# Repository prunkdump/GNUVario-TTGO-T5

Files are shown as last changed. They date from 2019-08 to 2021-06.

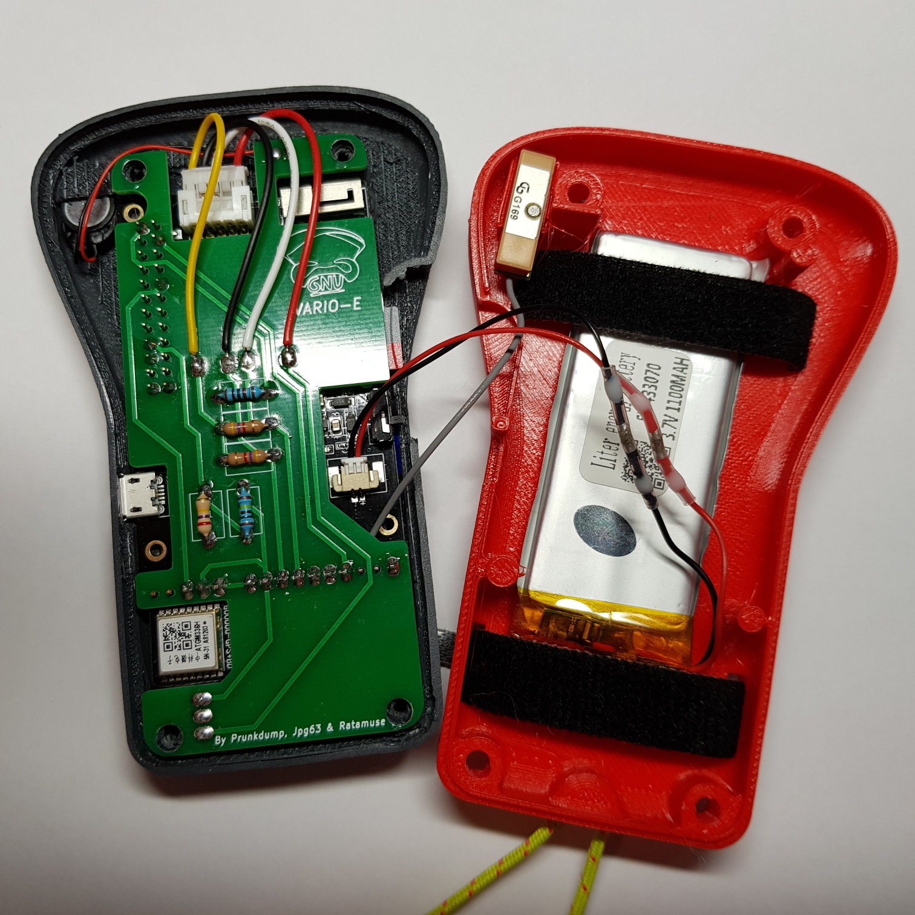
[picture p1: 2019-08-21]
PCB/KiCad GNU Vario E V1.12/Pictures/PCB soldered back.jpg

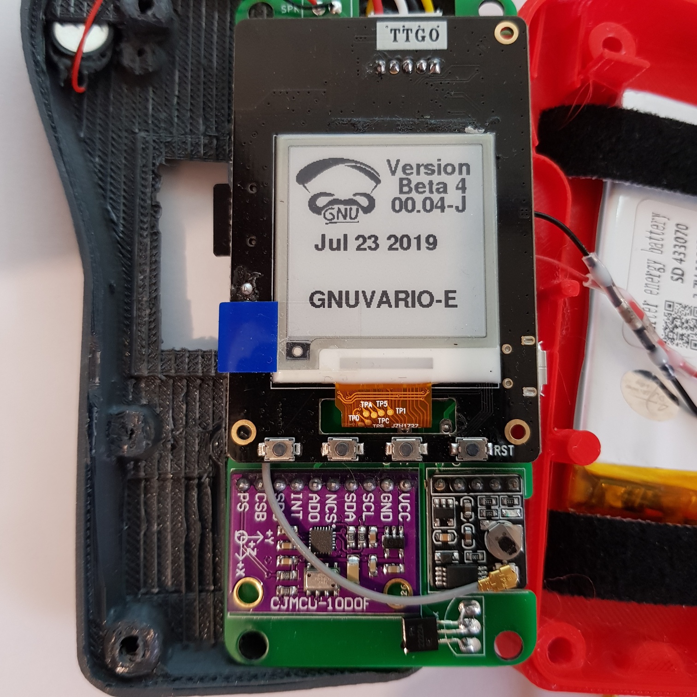
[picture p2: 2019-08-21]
PCB/KiCad GNU Vario E V1.12/Pictures/PCB soldered front.jpg

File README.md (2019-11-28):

# Gnuvario_for_TTGO-T5
# GNUVARIO-E     Stable version ---
# GNUVARIO-E     Developpement version 0.6 beta 7
# PCB            version 2.1
# 3D CASE        version 2.01

 v 0.1                              beta 1 version                     
 v 0.2     beta 1      23/06/19     debug VarioScreen                        
 v 0.3     beta 1      25/06/19     correction mesure tension          
                                    correction mesure de vitesse       
 v 0.3     beta 2      26/06/19     correction save IGC                                                 
 v 0.4     beta 1      03/07/19     ajout la coupure du son            
 v 0.4     beta 2      06/07/19     ajout statistique                  
 v 0.4     beta 3      18/07/19     Correction gestion Eeprom          
                                    Correction tache affichage          
                                    Ajout delete task display          
                                    Correction affichage statistique   
 v 0.4      beta 4      22/07/19    Correction effacement screendigit                               
                                    Correction affichage duree du vol  
                                    Correction affichage statistique   
                                    Modification FlightHistory         
                                    Ajout parametre flighthistory dans 
                                    SETTINGS.TXT                       
                                    Enregistrement des statistique     
                                    toutes les 60sec - reduction des   
                                    cycle d'ecriture dans la mémoire   
                                    flash de l'ESP32                   
 v 0.4     beta 5    24/07/19       Ajout TrendDigit                   
                                    Modification TrendLevel            
                                    Modification screendigit           
                                    Correction démarrage du vol    
 v 0.4     beta 6    25/07/19       Ajout NO_RECORD                                                                                          
                                    Correction TWOWIRESCHEDULER        																		
 
 v 0.4     beta 7    05/08/19       Désactivation enregistrement stat  
                                    pour eviter le bug du plantage      
                                    Ajout paramettre wifi              
                                    Modification SETTINGS.TXT v1.2     
 v 0.4     beta 8    06/08/19       Ajout icone Norecord               
                                    Correction bug statistique         
                                    Raffraichissement de l'ensemle de  
                                    l'écran toutes les 30sec           
 v 0.5     beta 1    10/08/19       Ajout Gestionnaire d'erreur ESP32  
                                    Mise à jour via SDCARD /update.bin 
                                    Ajout Serveur Web update/download  
                                    Ajout HAVE_WIFI                    
                                    Ajout BT                           
 v 0.5     beta 2    20/08/19       Ajout dans hardwareConfig32 de la  
                                    version du PCB et de la TTGO       
                                    Ajout lecture de la temperature    
                                    MAJ OTA Web serveur                
                                    Ajout changement de page           
                                    Ajout 2ème ecran                   

 v 0.5     beta 3  25/08/19         Ajout LOW/HIGH level cmd ampli     
                                    Ajout ecran reglage volume du son  
                                    Correction Bug bouton              

 v 0.5     beta 4  30/08/19         Ajout écran stat 
                                    Modification librairie ToneHAL 
																		Correction bug d'affichage mineurs

 v 0.5     beta 5  31/08/19         Correction bg reglage volume       
                                    Ajout commande ampli dans loop     
                                    pour test                          
 
 v 0.5     beta 6  04/09/19         Changement librairies MS5611 et MPU9250                                                             
                                    Modification de la calibration de l'altitude par le GPS                  
                                    Ajout d'un coeficiant de compensation de temperature             
                                    Modification de la séquence de démarrage de l'enregistrement   
																		
 v 0.5     beta 7  10/09/19         Ajout choix des pin SDA, SCL                                                                                                       
                                    Modification des librairies du MPU9250 / ajout fonctions de                                                                                   
                                    Calibration                                                      
                                    Ajout Son de monté variable                                      
                                    Modification de la sequence de démarrage -                       
                                    allongement du temps de l'écran de stat à 6 sec                  
                                    init MS5611 avant ecran stat, ajout acquisition durant ecran     
                                    stat et init kalman après                                        
                                    Ajout d'un paramettre de nombre d'acquisition du GPS avant        
                                    la mise à jour de Altitude Barometrique                          
                                    Modification librairie EEPROM                                    
																		
                   Developpement à venir                               
                                                                                                                                    
 V0.4                                                                                                                                          																												
 bug affichage finesse  
 
 V0.5                                                                  
 voir réactivité des données GPS                                                                     
 Probleme consommasion - SDcard - deep slepp                                                         
                                                                                                     
 v0.6                                                                                                   
 MODIF - Refaire gestion Eeprom avec preference                                                      
 AJOUT - Calibration MPU                                                                                                              
 AJOUT - gestion du MPU par Interruption                                                             
 BUG   - reboot à l'init du MPU  - nan lors du first alti                                            
 BUG   - blocage MPU - plus de valeur valide                                                         
 BUG   - temperature                                                                                 
 BUG   - DISPLAY_OBJECT_LINE object ligne ne fonctionne pas                                          
 AJOUT - Créer une bibliothèque de log (debug)  avec fichier de log                                  
 BUG   - Alti erreur deep sleep non validé                                                               
 BUG   - Norcissement de l'écran                                                                     
                                                                                                     
 VX.X                                                                                                
 Paramètrage des écrans                                                                             
 Gérer le son via le DAC                                                                             
 revoir volume du son ToneESP32                                                                      
 Refaire gestion du son (parametrage via xctracer)                                                   
 Ecran position afficher les coordonées GPS, la boussole, et l'altitude                                                                                                     
 Création dynamique des objets screen                                                                
 Sens et vitesse du vent                                                                             
 Carnet de vol (10 derniers vols)                                                                    
 verifier fonctionnement BT                                                                          
 Recupération vol via USB                                                                                                                                                                    
 Ecran 2.9'' en vertical                                                                             

                    Fonctionalitées   
		
  Version 0		
    Vario précis avec capteur de pression et accéleromètres
    GPS
    Enregistrement des vols sur carte SD
    Affichage sur ecran E-Ink
    Affichage du vario, de l'altitude, de la vitesse sol,
    de l'heure, du temps de vol, ...
                                                                       
  Version 0.3                                                                                                                               
    Parametre utilisateur dans fichier SETTINGS.TXT                    
    Coupure du son via le bouton central (en vol)                      
                                                                       
  Version 0.4                                                          
    Statistiques de Vol                                                
    taux de chute et finesse                                           
    indicateur de monte/descente 
    Désactiver l'enregistrement des vols		
                                                                       
  Version 0.5                                                            
    Mise à jour via la carte SD (update.bin)                            
    Récupération des vol via Wifi                                         
    Mise à jour via Wifi                                                  
    Upload des fichiers de configuration via Wifi                         
    Ajout Bluetooth                                                       
    Multi-écran (ajout 2ème page / gestion des bouton droit et gauche)    
    Affichage de la température        
		Page de configuration du volume sonore   
    Page de statistique accessible via les boutons    	
		Mise en veille automatique en cas de batterie trop faible               
                                                                              
  Version 0.6                                                              
    Page de calibration                                                      
    Mise en veille prolongée par bouton                                                  
    Ajout gestion des écran 2.9'' et 2.13''                                  
    Ajout du serveur Web sur SDCARD                                          
    Activation du Bluetooth en parametre dans le fichier de configuration       
    Ajout de titre au dessus des champs de données                          
    Ajout de nouveau objects screen - ligne - rose des vents                
    Modification de l'organisation des fichiers sur la carte SD                
    Ajout compensation de température         
    Ajout correction d'altitude GPS                     
    Modification calibration alti GPS - 5 mesures puis moyenne de l'altitude sur 10 mesures avant de calibrer le barometre                   
    3 fichiers de paramètrage params.jso, wifi.cfg, variocal.cfg               
    Gestion automatique de la mise à jour du fichier params.jso en cas d'ajout ou de suppréssion de champs                                       
    Mise en veille en cas d'inactivité, paramètrable - 0 infini

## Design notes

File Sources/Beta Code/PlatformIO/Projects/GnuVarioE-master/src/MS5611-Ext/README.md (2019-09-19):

Arduino-MS5611
===============

MS5611 Barometric Pressure & Temperature Sensor Arduino Library

This library use I2C to communicate, 2 pins are required to interface.

Read more: http://www.jarzebski.pl/arduino/czujniki-i-sensory/czujnik-cisnienia-i-temperatury-ms5611.html

MS5611

MS5611

I need your help
----------------

July 31, 2017

In the near future I plan to refactoring the libraries. The main goal is to improve code quality, new features and add support for different versions of Arduino boards like Uno, Mega and Zero.

For this purpose I need to buy modules, Arduino Boards and lot of beer. 

If you want to support the further and long-term development of libraries, please help.

You can do this by transferring any amount to my PayPal account: paypal@jarzebski.pl

Thanks!

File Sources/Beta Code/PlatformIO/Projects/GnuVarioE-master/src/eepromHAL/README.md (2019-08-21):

# EEPROMHAL Library

EepromHAL is an arduino abstraction library for Eeprom management 
									
Multi-platform :
									Arduino Pro-Mini
									Atmel SAM D21 - MKZERO 
									Espressif ESP32
									
## Setting

	in eepromHAL.h

									EEPROM_SIZE 					Eeprom size alocation

									EEPROMHAL_EXTENDED		Activate extended function

##	VERSION 1.3.3

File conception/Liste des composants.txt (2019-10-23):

Gnuvario-E

Version 2.0

Liste des composant :

- une carte TTGO-T5 version 2.4 avec écran 1.54
[AE] ttgo-T5 v2.4

- CJMCU_117 MPU-9250+MS5611 Haute précision 9-Axes 10DOF
[AE] CJMCU 117
[EB] CJMCU 117

- GPS ATGM336H
[AE] ATGM336H
{EB] ATGM336H

- Batterie lipo 3.7V 1100mAH 30x70x4.3
[AE] lipo 3.7V 1100mAH 4.3
https://fr.aliexpress.com/item/32662685911.html?spm=a2g0s.9042311.0.0.e0e06c37J9dtAU

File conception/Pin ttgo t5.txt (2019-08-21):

*****************
MPU 9250 / MS5611
*****************
 
SDA_PIN 	21
SCL_PIN 	22

*******************
Ecran EPaper 1.54''
*******************

CS/SS 		GPIO 5
DC 		GPIO17
RST 		GPIO16
BUSY 		GPIO 4

MOSI		15
MISO		2
SCK		14

https://github.com/ZinggJM/GxEPD

****
LED
**** 

LED_BUILTIN 	22

*******
SDCard
*******

mySD.h

M5Stack.h

CS 		13
MOSI		15
MISO		2
SCK		14

*********
Boutons
*********

M4Stack.h

Bouton A	38
Bouton B	37
Bouton C	39

************
Speaker
************

PWM/DAC		25 ou 26

 NS4148, http://www.chipsourcetek.com/Uploads/file/20151207193630_0605.pdf amplificateur audio mono 3W - Classe D connecté sur la pin GPIO 25

(XT_DAC_Audio) for ESP32  http://www.xtronical.com/the-dacaudio-library-download-and-installation/ 

pinAudioAmpEna	34

******************
GPS
******************

RX	IO19

******************************
Lecture de la charge batterie
******************************

tension  IO35	

Les données sont imparfaites sur internet. Je suis reparti de la base: Le shéma du Adafuit ESP32 HUZZAH feather. 
https://github.com/adafruit/Adafruit-HUZZAH32-ESP32-Feather-PCB

On y voit que le "pont diviseur" entre VBAT et l'entrée analogique A13 "sacrifiée" à la tâche de mesure de la tension batterie 
est constitué de deux résistances de 100K.

            vbat
             |
            100k
             |
  A13 IO35 ---
             |
            100k
             |
            GND

D'autre part dans le datasheet ESP32 on voit que l'ADC est sur 12 bits (0--4095) avec une "full range" à Vcc soit 
environ 3.2V (3.29 dans mon cas)

Donc :

La tension mesurée est V bat / 2
Le tout avec 0=0v et 4095=Vcc (3.2V)
Donc de facon générique l'entrée analogique est convertie en Volts par

U=analogRead/(4096/Vcc)
Donc pour VBAT sur A13

Vbat=2*analogRead/(4096/Vcc)

/*********************************/
Internal HALL Sensor
/*********************************/

/* 
 *  Copyright (c) 2018, circuits4you.com
 *  All rights reserved.
 * 
 * ESP32 Hall Sensor Example
 */

 #define LED 22
 
//================================================
//         Setup
//================================================
void setup() {
  Serial.begin(115200);
  pinMode(LED,OUTPUT);
}

//================================================
//         Loop
//================================================
void loop() { 
  int sensor = hallRead();  //Reads Hall sensor value
  Serial.print("Sensor Reading:");
  Serial.println(sensor);

  digitalWrite(LED,(sensor < 0) ? HIGH : LOW); //On board LED detects presence of magnet
  delay(500);
}

/*************************************************
Internal TEMPERATURE Sensor
/*************************************************

/* 
 *  https://circuits4you.com
 *  ESP32 Internal Temperature Sensor Example
 */

 #ifdef __cplusplus
  extern "C" {
 #endif

  uint8_t temprature_sens_read();

#ifdef __cplusplus
}
#endif

uint8_t temprature_sens_read();
//====================================================
//         Setup
//====================================================
void setup() {
  Serial.begin(115200);
}

//====================================================
//         Loop
//====================================================
void loop() {
  Serial.print("Temperature: ");
  
  // Convert raw temperature in F to Celsius degrees
  Serial.print((temprature_sens_read() - 32) / 1.8);
  Serial.println(" C");
  delay(1000);
}

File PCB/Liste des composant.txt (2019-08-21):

Gnuvario-E

Version 1.10

Liste des composant :

- une carte TTGO-T5 version 1.2 avec écran 1.54
[AE] ttgo-T5 v1.2

- CJMCU_117 MPU-9250+MS5611 Haute précision 9-Axes 10DOF
[AE] CJMCU 117
[EB] CJMCU 117

- GPS ATGM336H
[AE] ATGM336H
{EB] ATGM336H

- Batterie lipo 3.7V 1100mAH 30x70x4.3
[AE] lipo 3.7V 1100mAH 4.3
https://fr.aliexpress.com/item/32662685911.html?spm=a2g0s.9042311.0.0.e0e06c37J9dtAU

- Transistor S8050 ou equivalent (2N2222)
- R1 : 270k
- R2 : 1M
- R3 : 4.7k
- R4 : 4.7k
- R5 : 1k
Option connecteur 2 x 12 pins

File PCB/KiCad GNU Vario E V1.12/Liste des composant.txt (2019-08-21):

Gnuvario-E

Version 1.10

Liste des composant :

- une carte TTGO-T5 version 1.2 avec écran 1.54
- CJMCU_117 MPU-9250+MS5611 Haute précision 9-Axes 10DOF
- GPS ATGM336H
- Batterie lipo 3.7V 1100mAH 30x70x4.3
- Transistor S8050 ou equivalent
- R1 : 270k
- R2 : 1M
- R3 : 4.7k
- R4 : 4.7k
- R5 : 1k
Option connecteur 2 x 12 pins

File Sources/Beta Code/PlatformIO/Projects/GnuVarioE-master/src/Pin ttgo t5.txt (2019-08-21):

*****************
MPU 9250 / MS5611
*****************
 
SDA_PIN 	21
SCL_PIN 	22
INT		13
AD0		GND
NCS <-> PS

*******************
Ecran EPaper 1.54''
*******************

CS/SS 		5
DC 		17
RST 		16
BUSY 		4

MOSI		15
MISO		2
SCK		14

https://github.com/ZinggJM/GxEPD

****
LED
**** 

LED_BUILTIN 	22

*******
SDCard
*******

mySD.h

M5Stack.h

CS 		13
MOSI		15
MISO		2
SCK		14

*********
Boutons
*********

M4Stack.h

Bouton A	38
Bouton B	37
Bouton C	39

************
Speaker
************

PWM/DAC		25 
PWM/DAC exter   26
Shutdown	34

 NS4148, http://www.chipsourcetek.com/Uploads/file/20151207193630_0605.pdf amplificateur audio mono 3W - Classe D connecté sur la pin GPIO 25

(XT_DAC_Audio) for ESP32  http://www.xtronical.com/the-dacaudio-library-download-and-installation/ 

******************
GPS
******************

RX	IO19

******************************
Lecture de la charge batterie
******************************

tension  IO35	

Les données sont imparfaites sur internet. Je suis reparti de la base: Le shéma du Adafuit ESP32 HUZZAH feather. 
https://github.com/adafruit/Adafruit-HUZZAH32-ESP32-Feather-PCB

On y voit que le "pont diviseur" entre VBAT et l'entrée analogique A13 "sacrifiée" à la tâche de mesure de la tension batterie 
est constitué de deux résistances de 100K.

            vbat
             |
            100k
             |
  A13 IO35 ---
             |
            100k
             |
            GND

D'autre part dans le datasheet ESP32 on voit que l'ADC est sur 12 bits (0--4095) avec une "full range" à Vcc soit 
environ 3.2V (3.29 dans mon cas)

Donc :

La tension mesurée est V bat / 2
Le tout avec 0=0v et 4095=Vcc (3.2V)
Donc de facon générique l'entrée analogique est convertie en Volts par

U=analogRead/(4096/Vcc)
Donc pour VBAT sur A13

Vbat=2*analogRead/(4096/Vcc)

/*********************************/
Internal HALL Sensor
/*********************************/

/* 
 *  Copyright (c) 2018, circuits4you.com
 *  All rights reserved.
 * 
 * ESP32 Hall Sensor Example
 */

 #define LED 22
 
//================================================
//         Setup
//================================================
void setup() {
  Serial.begin(115200);
  pinMode(LED,OUTPUT);
}

//================================================
//         Loop
//================================================
void loop() { 
  int sensor = hallRead();  //Reads Hall sensor value
  Serial.print("Sensor Reading:");
  Serial.println(sensor);

  digitalWrite(LED,(sensor < 0) ? HIGH : LOW); //On board LED detects presence of magnet
  delay(500);
}

/*************************************************
Internal TEMPERATURE Sensor
/*************************************************

/* 
 *  https://circuits4you.com
 *  ESP32 Internal Temperature Sensor Example
 */

 #ifdef __cplusplus
  extern "C" {
 #endif

  uint8_t temprature_sens_read();

#ifdef __cplusplus
}
#endif

uint8_t temprature_sens_read();
//====================================================
//         Setup
//====================================================
void setup() {
  Serial.begin(115200);
}

//====================================================
//         Loop
//====================================================
void loop() {
  Serial.print("Temperature: ");
  
  // Convert raw temperature in F to Celsius degrees
  Serial.print((temprature_sens_read() - 32) / 1.8);
  Serial.println(" C");
  delay(1000);
}

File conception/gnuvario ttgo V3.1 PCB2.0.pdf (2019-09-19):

## GNUVARIO-E TTGO T5 V1.6 ou 2.4

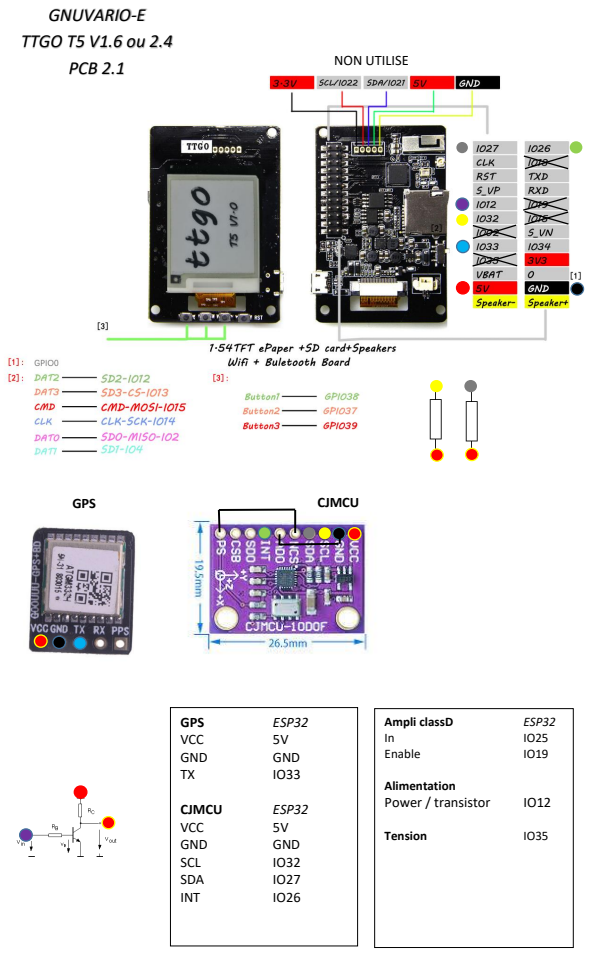
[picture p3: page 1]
GPS; ESP32; VCC; GND; CJMCU; SCL; SDA; INT; Ampli classD; Enable; Alimentation; Power / transistor; Tension; PCB 2.1; NON UTILISE

MPU 9250 / MS5611

SDA | IO27
SCL | IO32
INT | IO26

Ecran EPaper 1.54''

CS/SS | IO05
DC | IO17
RST | IO16
BUSY | IO04
MOSI | IO15
MISO | IO02
SCK | IO14

SDCard

CS | IO13
MOSI | IO15
MISO | IO02
SCK | IO14

Boutons

Bouton A | IO38
Bouton B | IO37
Bouton C | IO39

HP

PWM/DAC | IO25
Ampli (EN) | IO19

GPS

RX | IO33

Lecture de la charge batterie

Tension | IO35

Alimentation

Transistor | IO12

IO02 | MISO | SDCARD / E -INK
IO04 | BUSY | E -INK
IO05 | CS/SS | E -INK
IO12 | POWER | Transistor / POWER
IO13 | CS | SDCARD
IO14 | SCK | SDCARD / E -INK
IO15 | MOSI | SDCARD/E -INK
IO16 | RTS | E -INK
IO17 | DC | E -INK
IO19 | EN | Enable AmpliD
IO21 | SDA | MPU
IO22 | SCL | MPU
IO25 | PWM/DAC | HP
IO26 | INT | INT MPU9250
IO27 | SDA | SDA MPU9250
IO32 | SCL | SCL MPU9250
IO33 | TX | GPS
IO34
IO35 | VOLT | pont diviseur (100k/100K)
IO37 | BTN | Bouton B
IO38 | BTN | Bouton A
IO39 | BTN | Bouton C

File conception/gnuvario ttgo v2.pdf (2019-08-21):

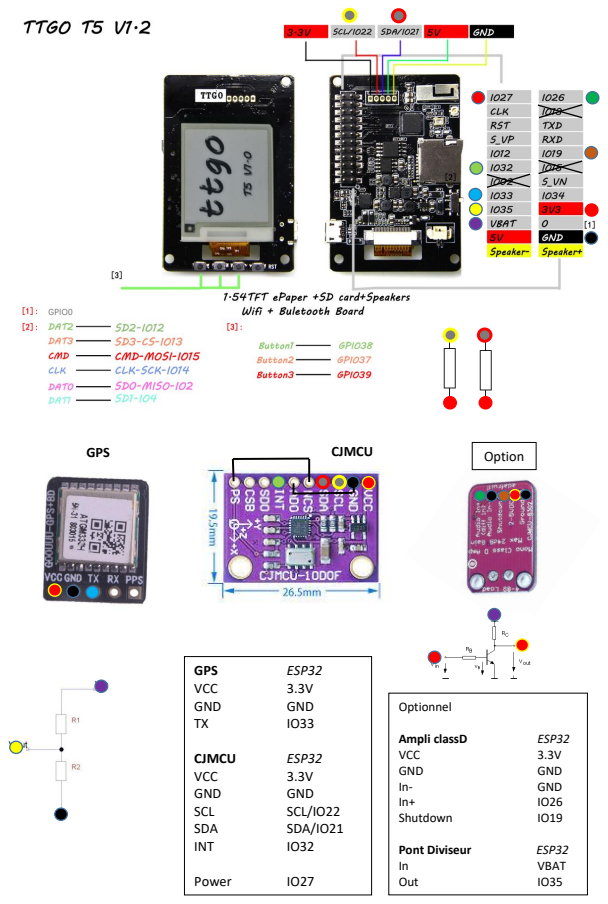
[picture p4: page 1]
GPS; ESP32; VCC; GND; CJMCU; SCL; SCL/IO22; SDA; SDA/IO21; INT; Power; Optionnel; Ampli classD; Shutdown; Pont Diviseur; VBAT; Out; Option GPS

MPU 9250 / MS5611

SDA | IO21 | Connecteur 5 pins
SCL | IO22
INT | IO32

Ecran EPaper 1.54''

CS/SS | IO05
DC | IO17
RST | IO16
BUSY | IO04
MOSI | IO15
MISO | IO02
SCK | IO14

SDCard

CS | IO13
MOSI | IO15
MISO | IO02
SCK | IO14

Boutons

Bouton A | IO38
Bouton B | IO37
Bouton C | IO39

HP

PWM/DAC | IO25

en option HP et ampli externe

PWM/DAC | IO26
pinAudioAmpEna | IO19

GPS

RX | IO33
TX | IO34

Lecture de la charge batterie

tension | IO35

IO02 | MISO | SDCARD / E-INK
IO04 | BUSY | E-INK
IO05 | CS/SS | E-INK
IO12
IO13 | CS | SDCARD
IO14 | SCK | SDCARD / E-INK
IO15 | MOSI | SDCARD/E-INK
IO16 | RTS | E-INK
IO17 | DC | E-INK
IO19 | | Enable AmpliD / Enable AmpliD Optionnel
IO21 | SDA | MPU
IO22 | SCL | MPU
IO25 | PWM/DAC | HP
IO26 | PWM/DAC | AmpliD optionnel
IO27 | | Transistor d’alimentation
IO32 | | INT MPU
IO33 | TX | GPS
IO34 | RX | GPS optionnel
IO35 | | pont diviseur (270k/1M) V2.4 (100k/100K)
IO37 | | Bouton B
IO38 | | Bouton A
IO39 | | Bouton C

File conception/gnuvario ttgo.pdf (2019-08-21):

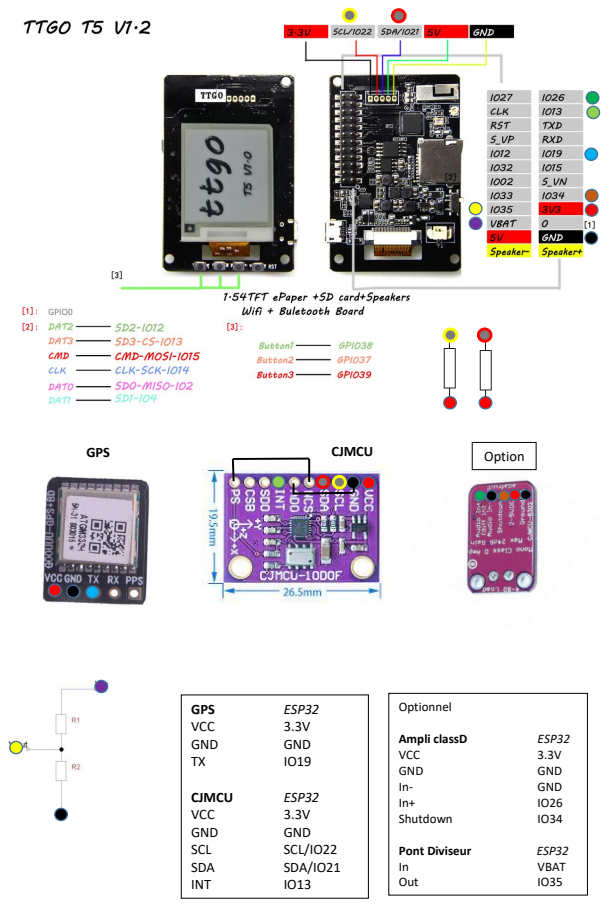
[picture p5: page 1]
GPS; ESP32; VCC; GND; CJMCU; SCL; SCL/IO22; SDA; SDA/IO21; INT; Optionnel; Ampli classD; Shutdown; Pont Diviseur; VBAT; Out; Option GPS

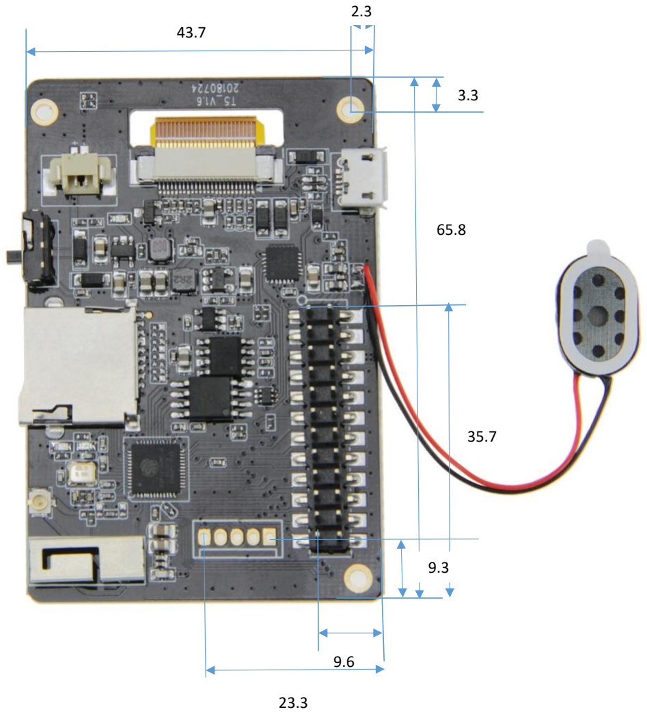
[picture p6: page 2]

43.7

65.8

35.7

9.6

2.3

3.3

23.3

9.3

GPS : ATGM336H

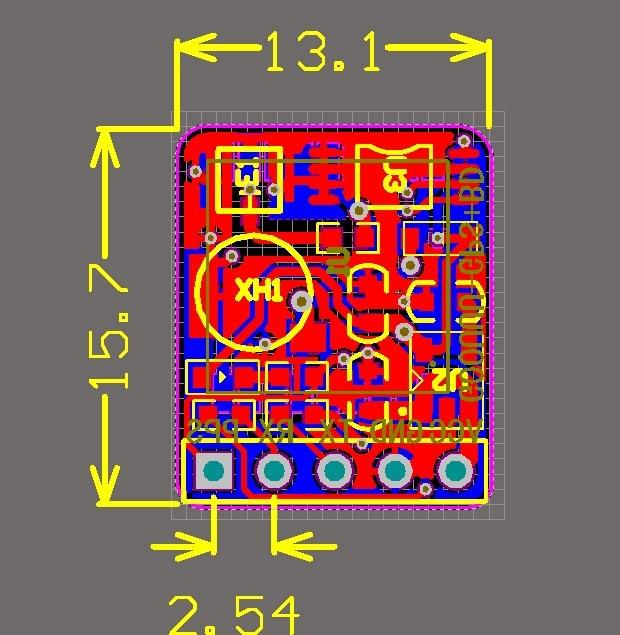
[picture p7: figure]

Ampli class D

# PAM8302

- PAM8302A datasheet (https://cdn-shop.adafruit.com/datasheets/PAM8302A.pdf)
- https://cdn-shop.adafruit.com/datasheets/PAM8302A.pdf
- EagleCAD PCB files on GitHub (https://github.com/adafruit/Adafruit-PAM8302-Mono-Amplifier-PCB)
- https://github.com/adafruit/Adafruit-PAM8302-Mono-Amplifier-PCB
- Fritzing object available in Adafruit Fritzing library (https://github.com/adafruit/Fritzing-Library)
- https://github.com/adafruit/Fritzing-Library

Dimensions (without 0.1" header):

- 15mm x 24mm x 2mm / 0.6" x 0.9" x 0.08"
- Weight: 1.4g

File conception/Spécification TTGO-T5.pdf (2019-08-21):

Espressif's ESP32 is one of the most unique microcontrollers on the market. Its laundry list of features include:

- Dual-core Tensilica LX6 microprocessor
- Up to 240MHz clock frequency
- 520kB internal SRAM
- Integrated 802.11 BGN WiFi transceiver
- Integrated dual-mode Bluetooth (classic and BLE)
- 2.2 to 3.6V operating range
- 2.5 µA deep sleep current
- 32 GPIO
- 10-electrode capacitive touch support
- Hardware accelerated encryption (AES, SHA2, ECC, RSA-4096)

ESP32 Technical Specifications

Microprocessor | Tensilica Xtensa LX6
Maximum Operating Frequency | 240MHz
Operating Voltage | 3.3V
Analog Input Pins | 12-bit, 18 Channel
DAC Pins | 8-bit, 2 Channel
Digital I/O Pins | 39 (of which 34 is normal GPIO pin)
DC Current on I/O Pins | 40 mA
DC Current on 3.3V Pin | 50 mA
SRAM | 520 KB
Communication Wi-Fi Bluetooth | SPI(4), I2C(2), I2S(2), CAN, UART(3) 802.11 b/g/n V4.2 – Supports BLE and Classic Bluetooth

VSPI | GPIO23 (MOSI), GPIO19(MISO),
GPIO18(CLK) and GPIO5 (CS)
Used | for | SPI-1
communication.
HSPI | GPIO13 (MOSI), GPIO12(MISO), GPIO14(CLK) and GPIO15 (CS) | Used for SPI-2 communication.
IIC | GPIO21(SDA), GPIO22(SCL) | Used for I2C communication.

CONNECTEURS

IO27 | ADC2.7 | GPIO27 | Touch7 | | 27
SCK
RST | | Reset
S_VP SenseVP | GPPIO36 | ADC1_0 | 36
IO12 | ADC2_5 | GPIO12 | HSPI_O | Touch4 | 12
IO32 | XTAL32 | GPOI32 | ADC1_4 | Touch9 | 32
IO02 | CS | GPIO2 | ADC2_2 | HSPI_WP | 2
IO33 | XTAL32 | GPIO33 | ADC1_5 | Touch8 | 33
IO35 | | GPIO35 | ADC1_7 | | 35
VBAT
5V
Speaker-
IO26 | DAC2 | GPIO26 | ADC2_8 | | 26
IO13 | ADC2_4 | GPIO13 | HSPI_ID | | 13
TXD | CLK3 | GPIO1 | U0_TX | | TX
RXD | CLK2 | GPIO3 | U0_RX | | RX
IO19 | MISO | GPIO19 | V_SPI_O | | 19
IO15 | ADC2_2 | GPIO15 | HSPI_CS0 | | 15
S_VN SensVN | GPIO39 | ADC1_3 | 39
IO34 | ADC1_6 | GPIO34 | | | 34
3V3
0 | CLK1 | GPIO0 | ADC2_1 | Touch0 | 0
GND
Speaker+

3-3V
IO22 | SCL | GPIO22 | V_SPI_WP | 22
IO21 | SDA | GPIO21 | V_SPI_HD | 21
5V
GND

SDA_PIN | GPIO21 | I2C
SCL_PIN | GPIO22
MOSI | GPIO15 | SPI (SCREEN / SDCARD)
MISO | GPIO2
SCK | GPIO14
CS | GPIO5 | SCREEN
CS | GPIO13 | SDCARD
DC | GPIO17 | SCREEN
RST | GPIO16
BUSY | GPIO 4
BT1 | GPIO38
BT2 | GPIO37
BT3 | GPIO39
LED | GPIO22
GPIO00 | CLK1
GPIO01 | TX | UART
GPIO02 | MISO | SPI | SCREEN / SDCARD
GPIO03 | RX | UART
GPIO04 | BUSY SCREEN
GPIO05 | CS | SPI | SCREEN
GPIO12 | HSPI-O | HSPI
GPIO13 | HSPI-ID | HSPI | MPU (INT)
GPIO14 | SCK | SPI | SCREEN / SDCARD
GPIO15 | MOSI | SPI | SCREEN / SDCARD
GPIO16 | RST SCREEN
GPIO17 | DC SCREEN
GPIO19 | MISO | V-SPI-O | TX GPS
GPIO21 | SDA | I2C | MPU
GPIO22 | SCL | I2C | MPU / LED
GPIO25 | DAC1 | SPEAKER
GPIO26 | DAC2 | SPEAKER
GPIO27 | POWER CARD
GPIO32 | XTAL32 | RTC
GPIO33 | XTAL32 | RTC
GPIO34
GPIO35 | VBAT MESURE
GPIO36 | S_VP | SenseVP
GPIO37 | | | BT1
GPIO38 | | | BT2
GPIO39 | S_VN | SenseVN | BT3 | HALL SENSOR

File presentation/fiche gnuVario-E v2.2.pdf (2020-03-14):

# Vario-E

Le GnuVario-E est un variomètre communautaire à assembler soi-même. Développé par une poignée d’amateurs bénévoles, il est libre de droit, open Source et Open Hardware.

Conçu avec des composants simples à se procurer et à souder. Il est possible de fabriquer ou faire fabriquer par un professionnel, le boitier 3D et le PCB (circuit imprimé).

Le coût de ce vario est d’environ 65€

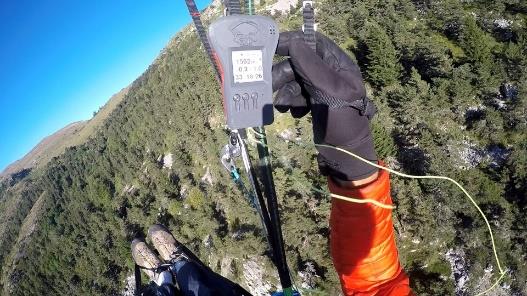
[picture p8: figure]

A travers le forum, tout le monde peut contribuer à le faire évoluer.

La fabrication ne demande qu’une vingtaine de soudures, le reste peut être acheté sur internet.

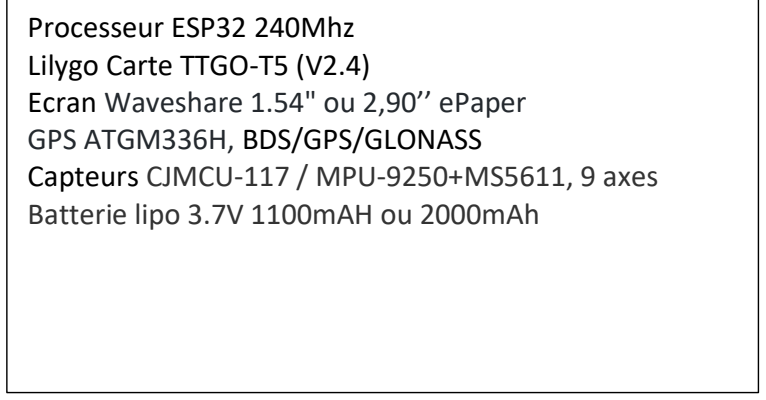
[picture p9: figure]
Processeur ESP32 240Mhz Lilygo Carte TTGO-T5 (V2.4) Ecran Waveshare 1.54" ou 2,90’’ ePaper GPS ATGM336H, BDS/GPS/GLONASS; Batterie lipo 3.7V 1100mAH ou 2000mAh

TOUTES LES INFORMATIONS SONT DISPONIBLES :

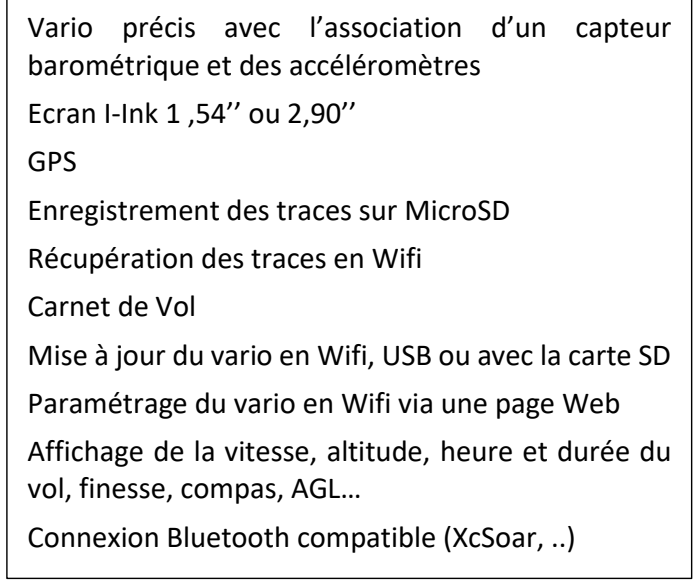
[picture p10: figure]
barométrique et des accéléromètres; Ecran I-Ink 1 ,54’’ ou 2,90’’; GPS; Enregistrement des traces sur MicroSD; Récupération des traces en Wifi; Carnet de Vol; vol, finesse, compas, AGL…

Sur le site Web du Projet | : | https://prunkdump.github.io/GNUVario-TTGO-T5-website/
Sur le Forum | : | http://www.parapentiste.info/forum/developpements-hardware-software/diy-
gnuvario-variometre-opensource-openhardware-arduino-t48334.0.html;new;topicseen#new
Sur la page du projet | : | https://github.com/prunkdump/GNUVario-TTGO-T5

## Caractéristiques

Vario précis avec l’association d’un capteur

Mise à jour du vario en Wifi, USB ou avec la carte SD Paramétrage du vario en Wifi via une page Web Affichage de la vitesse, altitude, heure et durée du

Connexion Bluetooth compatible (XcSoar, ..)

## Spécifications

Capteurs CJMCU-117 / MPU-9250+MS5611, 9 axes

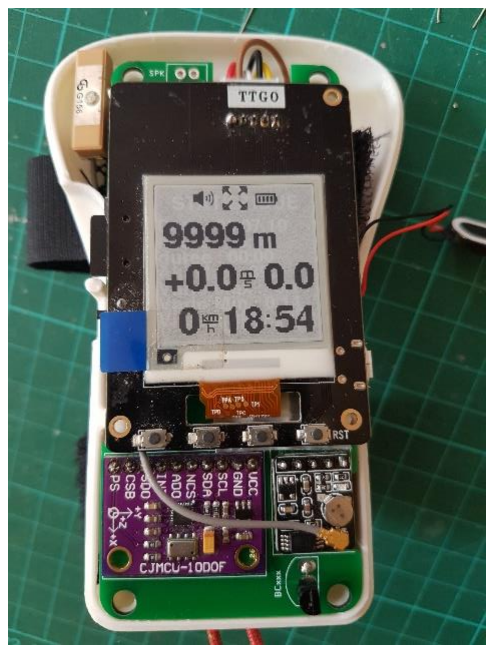
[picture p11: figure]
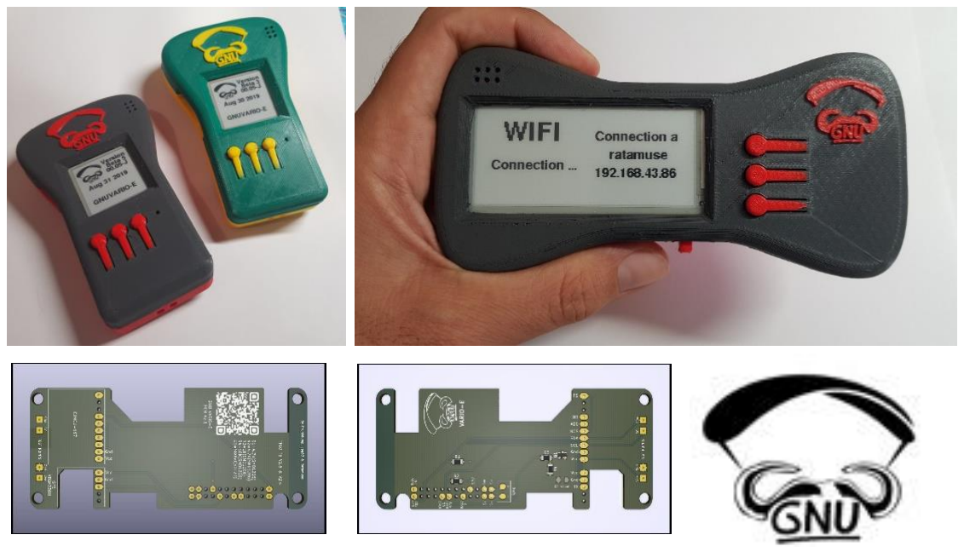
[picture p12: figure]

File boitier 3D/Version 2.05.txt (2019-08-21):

version 1.4	ajout trous pour le HP
		modification passage de la suspente de sécuritée
version 1.5	ajout de support pour le GPS et le HP.
		ajout d'un 4ème support pour la carte TTGO

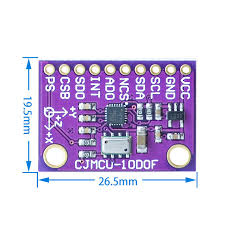
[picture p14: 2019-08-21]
conception/composants/CJMCU-1000F.jpg

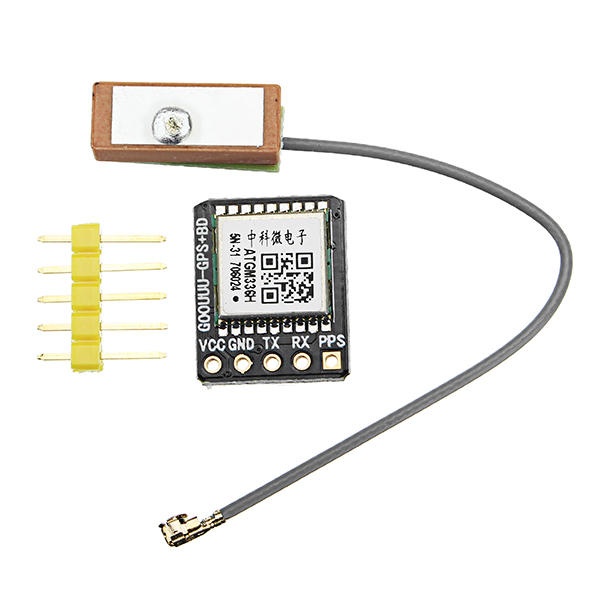
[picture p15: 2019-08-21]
conception/composants/ATGM336H.JPG

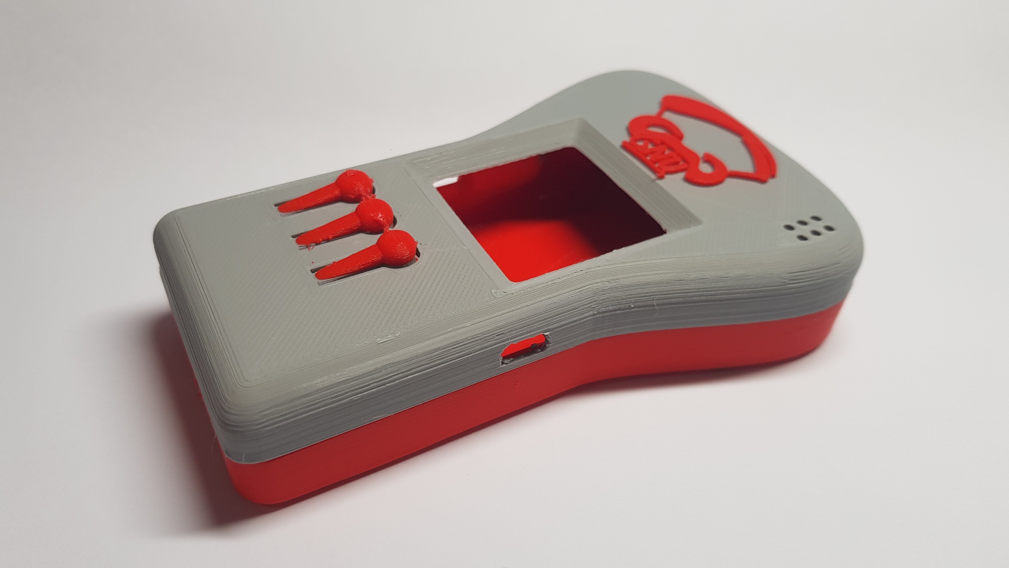
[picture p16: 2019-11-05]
Photos/Case/20191105_001520_resized.jpg

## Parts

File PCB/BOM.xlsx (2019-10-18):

Comment | Designator | Footprint | LCSC Part #（optional）
S8050 | Q1 | SOT-23 | C2146
4,7KΩ | R1 | 1206_R | C17936
4,7KΩ | R2 | 1206_R | C17936
1KΩ | R3 | 1206_R | C4410
10KΩ | R4 | 1206_R | C17902

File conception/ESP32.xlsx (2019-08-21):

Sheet: Tabelle1
 | ESP8266 | ESP32
 | Tensilica L106 32-bit single core micro controller | Xtensa® Single-/Dual-core 32-bit LX6 microprocessor(s)
ROM | none | • 448 KB
RAM | 160kB | • 520 KB
RTC RAM | 768 Bytes | 8kB slow + 8kB fast
• QSPI flash/SRAM, | up to 1 x 16 MB | up to 4 x 16 MB
GPIOs | 17 | 36
Wi-Fi | 802.11 b/g/n/e/i | 802.11 b/g/n/e/i
Bluetooth | no | yes
PWM Pins | 8 Software | 1 Hardware/16 software
ADC | 10 bit | 12 bit
DAC | no | 2 x 8 bit
Touch sensor | no | 10
Temperature Sensor | no | yes
Cryptographic engine | no | yes
• Power supply: | 2.5V to 3.6V | 2.3V to 3.6V

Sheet: Tabelle2
No. | Name | Type | GPIO | RTC_GPIO | ADC | TOUCH | Analog Pre-Amplifier | DAC | SD/SDIO/MMC Host Controller | UART | Parallel QSPI | JTAG | SDIO Slave | Ethernet | SD/SDIO/MMC Host Controller
25 | IO00 | I/O | GPIO00 | RTC_GPIO11 | ADC2_CH01 | TOUCH1 |  |  |  |  |  |  |  | EMAC_TX_CLK |  | CLK_OUT1
35 | TXD0 | I/O | GPIO01 |  |  |  |  |  |  | U0TXD |  |  |  | EMAC_RXD2 |  | CLK_OUT3
24 | IO02 | I/O | GPIO02 | RTC_GPIO12 | ADC2_CH02 | TOUCH2 |  |  | HS2_DATA0 |  | HSPIWP |  |  |  | HS2_DATA0
34 | RXD0 | I/O | GPIO03 |  |  |  |  |  |  | U0RXD |  |  |  |  |  | CLK_OUT2
26 | IO04 | I/O | GPIO04 | RTC_GPIO10 | ADC2_CH0 | TOUCH0 |  |  | HS2_DATA1 |  | HSPIHD |  |  | EMAC_TX_ER | HS2_DATA1
29 | IO05 | I/O | GPIO05 |  |  |  |  |  |  |  | VSPICS0 |  |  | EMAC_RX_CLK | HS1_DATA6
20 | SCK/CLK* | I/O | GPIO06 | UNUSABLE !!! (Flash memory) |  |  |  |  |  | U1CTS | SPICLK |  | SD_CLK |  | HS1_CLK
21 | SDO/SD0* | I/O | GPIO07 | UNUSABLE !!! (Flash memory) |  |  |  |  |  | U2RTS | SPIQ |  | SD_DATA0 |  | HS1_DATA0
22 | SDI/SD1* | I/O | GPIO08 | UNUSABLE !!! (Flash memory) |  |  |  |  |  | U2CTS | SPID |  | SD_DATA1 |  | HS1_DATA1
17 | SHD/SD2* | I/O | GPIO09 | UNUSABLE !!! (Flash memory) |  |  |  |  |  | U1RXD | SPIHD |  | SD_DATA2 |  | HS1_DATA2
18 | SWP/SD3* | I/O | GPIO10 | UNUSABLE !!! (Flash memory) |  |  |  |  |  | U1TXD | SPIWP |  | SD_DATA3 |  | HS1_DATA3
19 | SCS/CMD* | I/O | GPIO11 | UNUSABLE !!! (Flash memory) |  |  |  |  |  | U1RTS | SPICS0 |  |  |  | HS1_CMD
14 | IO12 | I/O | GPIO12 | RTC_GPIO15 | ADC2_CH05 | TOUCH5 |  |  | HS2_DATA2 |  | HSPIQ | MTDI |  | EMAC_TXD3 | HS2_DATA2
16 | IO13 | I/O | GPIO13 | RTC_GPIO14 | ADC2_CH04 | TOUCH4 |  |  | HS2_DATA3 |  | HSPID | MTCK |  | EMAC_RX_ER | HS2_DATA3
13 | IO14 | I/O | GPIO14 | RTC_GPIO16 | ADC2_CH06 | TOUCH6 |  |  | HS2_CLK |  | HSPICLK | MTMS |  | EMAC_TXD2 | HS2_CLK
23 | IO15 | I/O | GPIO15 | RTC_GPIO13 | ADC2_CH03 | TOUCH3 |  |  | HS2_CMD |  | HSPICS0 | MTDO |  | EMAC_RXD3 | HS2_CMD
27 | IO16 | I/O | GPIO16 |  |  |  |  |  |  | U2RXD |  |  |  | EMAC_CLK_OUT | HS1_DATA4
28 | IO17 | I/O | GPIO17 |  |  |  |  |  |  | U2TXD |  |  |  | EMAC_CLK_OUT_180 | HS1_DATA5
30 | IO18 | I/O | GPIO18 |  |  |  |  |  |  |  | VSPICLK |  |  |  | HS1_DATA7
31 | IO19 | I/O | GPIO19 |  |  |  |  |  |  | U0CTS | VSPIQ |  |  | EMAC_TXD0
33 | IO21 | I/O | GPIO21 |  |  |  |  |  |  |  | VSPIHD |  |  | EMAC_TX_EN
36 | IO22 | I/O | GPIO22 |  |  |  |  |  |  | U0RTS | VSPIWP |  |  | EMAC_TXD1
37 | IO23 | I/O | GPIO23 |  |  |  |  |  |  |  | VSPID |  |  |  | HS1_STROBE
10 | IO25 | I/O | GPIO25 | RTC_GPIO06 | ADC2_CH08 |  |  | DAC_1 |  |  |  |  |  | EMAC_RXD0
11 | IO26 | I/O | GPIO26 | RTC_GPIO07 | ADC2_CH09 |  |  | DAC_2 |  |  |  |  |  | EMAC_RXD1
12 | IO27 | I/O | GPIO27 | RTC_GPIO17 | ADC2_CH07 | TOUCH7 |  |  |  |  |  |  |  | EMAC_RX_DV
8 | IO32 | I/O | GPIO32 | RTC_GPIO09 | ADC1_CH04 | TOUCH9 |  |  |  |  |  |  |  |  |  | XTAL_32K_P (32.768kHz crystal oscillator input)
9 | IO33 | I/O | GPIO33 | RTC_GPIO08 | ADC1_CH05 | TOUCH8 |  |  |  |  |  |  |  |  |  | XTAL_32K_N (32.768kHz crystal oscillator outut)
6 | IO34 | I | GPIO34 | RTC_GPIO04 | ADC1_CH06
7 | IO35 | I | GPIO35 | RTC_GPIO05 | ADC1_CH07
4 | SENSOR_VP | I | GPIO36 | RTC_GPIO00 | ADC1_CH0 |  | SENSOR_VP |  |  |  |  |  |  |  |  | ADC_H
5 | SENSOR_VN | I | GPIO39 | RTC_GPIO03 | ADC1_CH03 |  | SENSOR_VN |  |  |  |  |  |  |  |  | ADC_H
1 | GND | P
2 | 3V3 | P
3 | EN | I
15 | GND | P
32 | NC
38 | GND | P
39 | GND | P

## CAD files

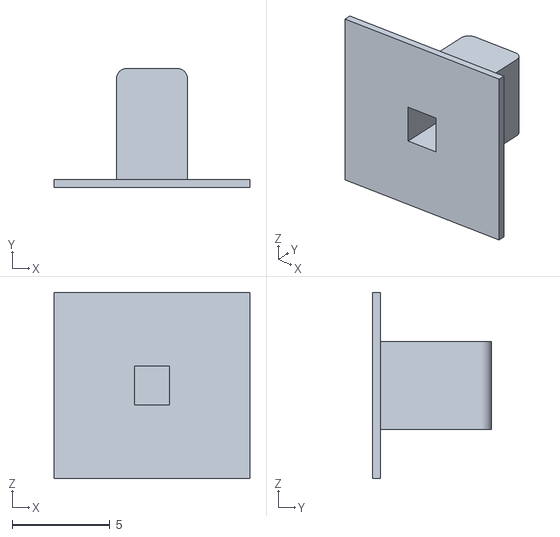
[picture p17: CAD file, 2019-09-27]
boitier 3D/capuchon slide switch/capuchon slide switch.STL
10.0 x 6.07 x 9.50

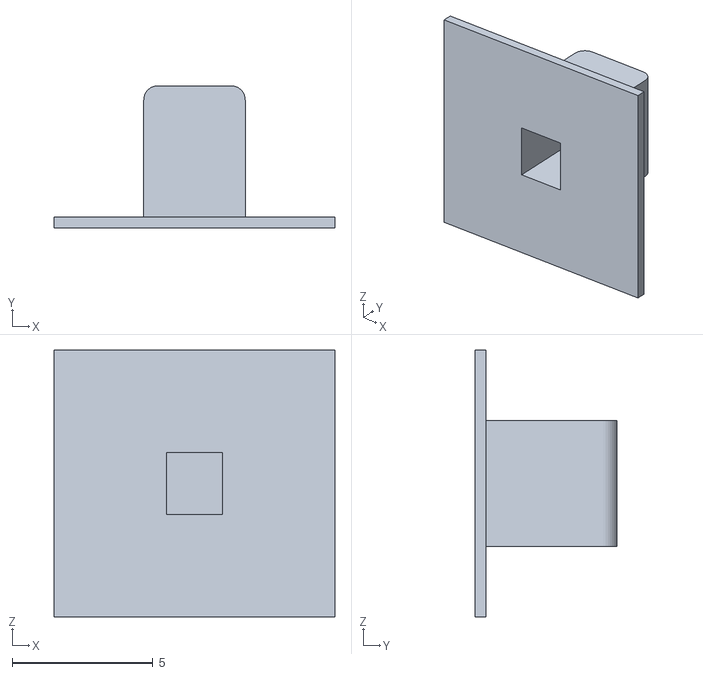
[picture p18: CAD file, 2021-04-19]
boitier 3D/Ecran 1.54''/capuchon slide switch/Slide switch cap.STL
10.0 x 5.07 x 9.50

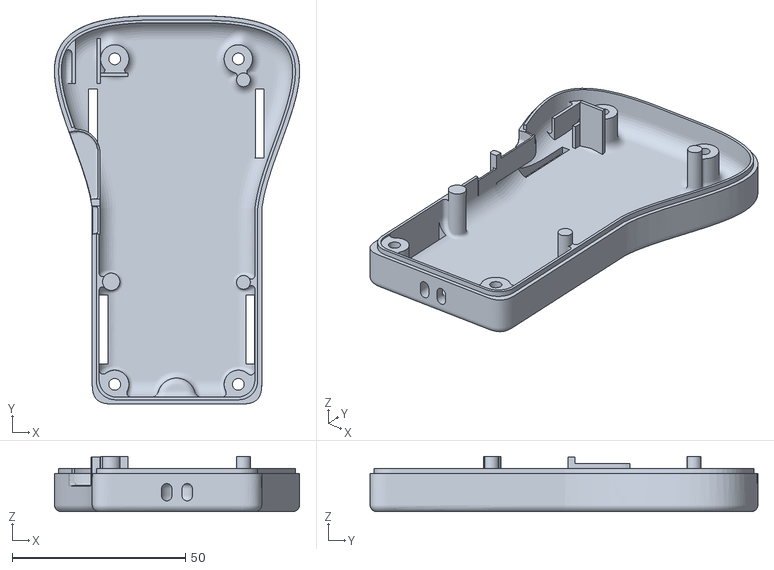
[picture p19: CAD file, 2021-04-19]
boitier 3D/Ecran 1.54''/Gnu bottom case/GNUVario-E-bottom 1100-20mm.STL
70.8 x 112.1 x 16.0

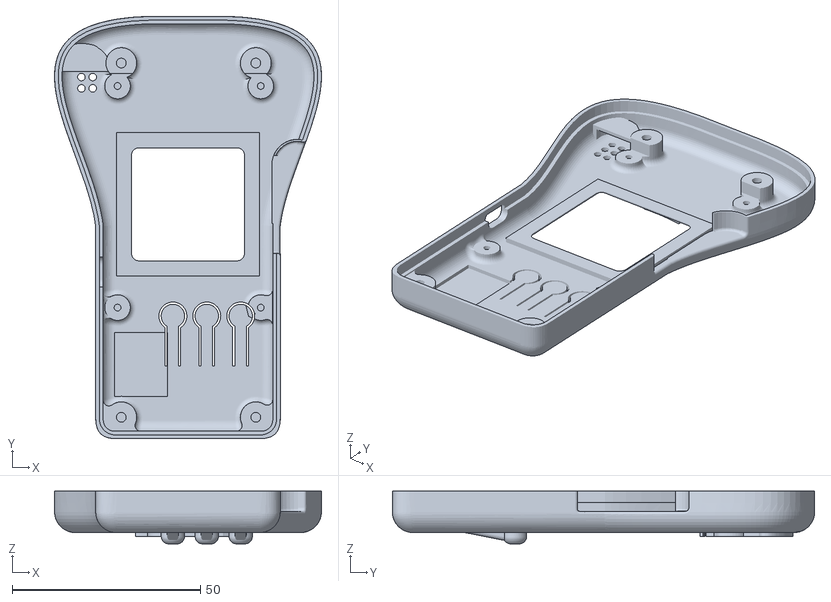
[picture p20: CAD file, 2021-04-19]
boitier 3D/Ecran 1.54''/Gnu top case/GNUVario-E-top-154.STL
70.8 x 112.1 x 14.0

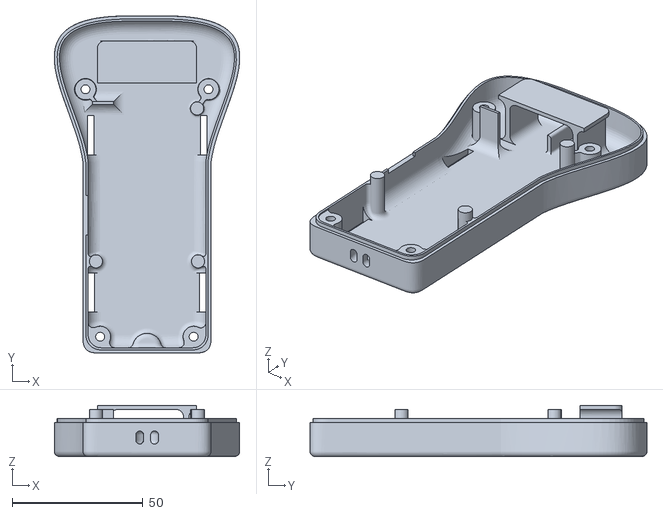
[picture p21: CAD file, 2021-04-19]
boitier 3D/Ecran 2.9'' portrait/GNUVario-E-291-bottom 2000-15mm.STL
70.8 x 128.7 x 19.5

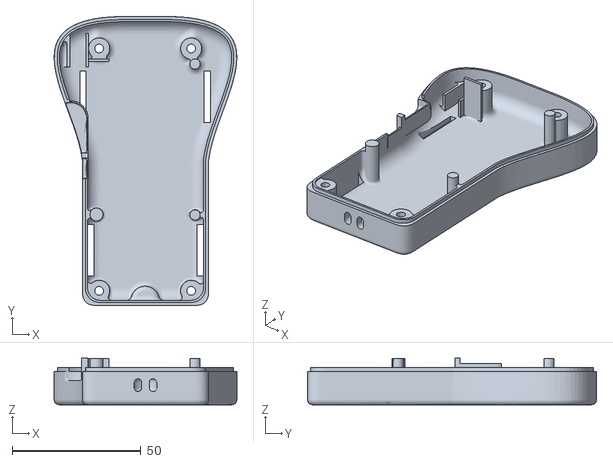
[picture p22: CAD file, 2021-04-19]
boitier 3D/Ecran 1.54''/Gnu bottom case/GNUVario-E-bottom 2000-20mm.STL
70.8 x 112.1 x 18.0

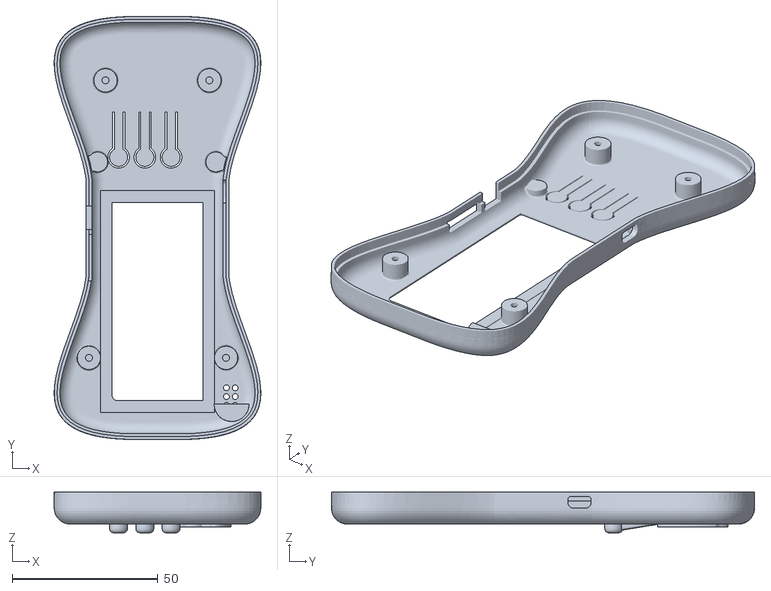
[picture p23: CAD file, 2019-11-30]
boitier 3D/Ecran 2.9''/cockpit GNU top case.STL
70.8 x 145.0 x 14.0

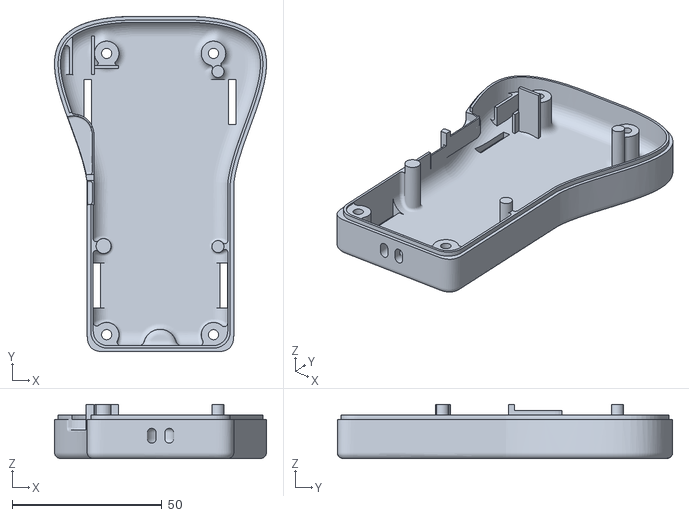
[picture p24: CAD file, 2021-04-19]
boitier 3D/Ecran 1.54''/Gnu bottom case/GNUVario-E-bottom 2000-15mm.STL
70.8 x 112.1 x 18.0

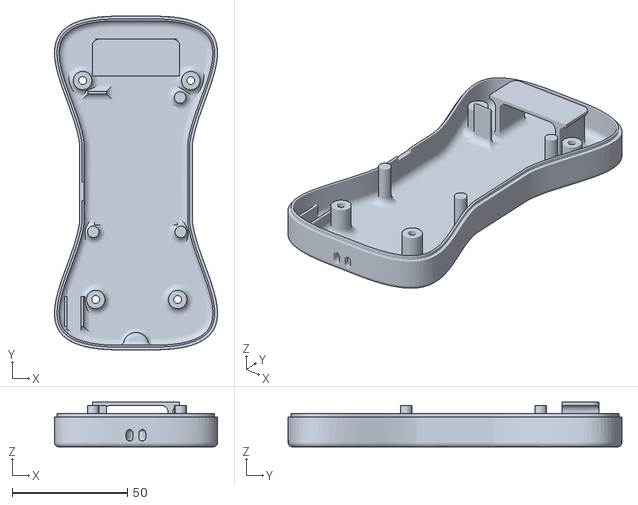
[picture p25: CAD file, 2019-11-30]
boitier 3D/Ecran 2.9''/cockpit GNU bottom case.STL
70.8 x 145.0 x 19.5

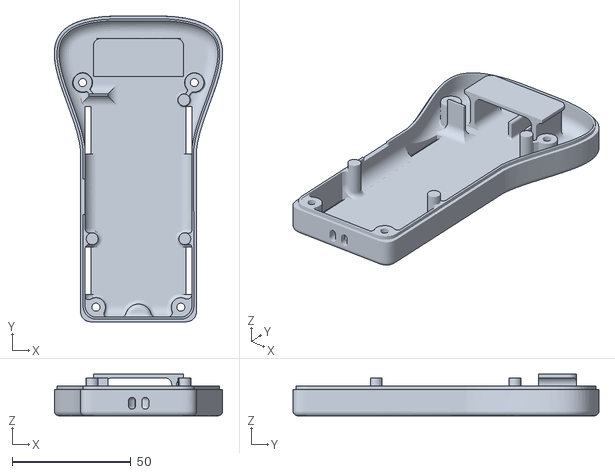
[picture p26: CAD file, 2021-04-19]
boitier 3D/Ecran 2.9'' portrait/GNUVario-E-291-bottom 1100-20mm.STL
70.8 x 128.7 x 17.5

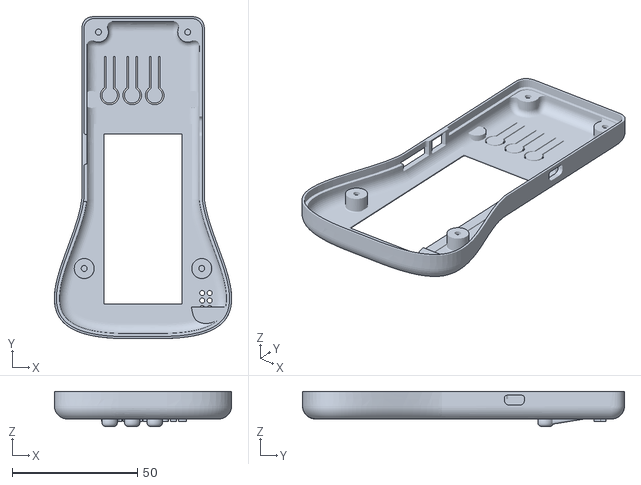
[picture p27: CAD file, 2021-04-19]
boitier 3D/Ecran 2.9'' portrait/GNUVario-E-291-top.STL
70.9 x 128.7 x 14.0

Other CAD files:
boitier 3D/Ecran 2.9''/GNU slide switch cap V2.STL
boitier 3D/Gnu bottom case/GNU bottom case.STL
boitier 3D/Gnu top case/GNU top case.STL
boitier 3D/Ecran 2.9'' portrait/GNUVario-E-291-bottom 2000-20mm.STL
boitier 3D/Ecran 1.54''/Gnu bottom case/GNUVario-E-bottom 1100-15mm.STL
boitier 3D/Ecran 2.9'' portrait/GNUVario-E-291-bottom 1100-15mm.STL
boitier 3D/Archive/Gnu bottom case/GNU bottom case.STL
boitier 3D/Archive/Gnu top case/GNU top case.STL
boitier 3D/Ecran 2.9''/GNU slide switch cap.STL

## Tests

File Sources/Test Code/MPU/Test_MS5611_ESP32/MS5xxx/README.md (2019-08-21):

arduino-ms5xxx
==============

Arduino Library with examples for using digital pressure sensors MS5607/MS5611 (and MS56xx, MS57xx, MS58xx) based on AN520 by manufacturer and the datasheets. This library has been tested extensively (over almost a year of datataking) with MS5607 and also tested newer MS5611 sensors. 
Note the different I2C-addresses, calculations and correction functions between the different chips. One generic MS5xxx-class as well as a derived class MS5611 with the new I2C address and the new calculations have been implemented.

The examples nicely show how to use this library with the standard MS5xxx-class. For usage with MS5611 chips just use the class MS5611 in the same way.
"Standard units" are Pascals for pressure and 0.01 °C for temperature as calculations are done exactly as shown in the manufacturers datasheet.

<a href="http://dx.doi.org/10.5281/zenodo.11966"><a>

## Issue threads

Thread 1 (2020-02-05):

Thank you for this project

ketan, 2020-02-05:
Hi.

I was looking to build a vario with an epaper display, and stumbled upon this project. This seems exciting enough and I'm looking to contribute in any way I can.

I'm unsure where and how I can be of help. So let me know.

Thanks

michelpa, 2020-02-29:
Hello,

Thank you for your message.

Any help is welcome: esp32 coding, web coding, web design (missing), documentation, translation, tests....

Let us know!

Pascal

PS: there is also a forum with a lot of information but in french:
http://www.parapentiste.info/forum/developpements-hardware-software/diy-gnuvario-variometre-opensource-openhardware-arduino-t48334.2125.html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

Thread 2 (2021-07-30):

Banggood/Aliexpress links for components?

ketan, 2021-07-30:
Hi,

The [component list](https://prunkdump.github.io/GNUVario-TTGO-T5-website-EN/materiel/composants.html) says that I should use lilygo t5 with epaper display GDEW029M06 from Good Display.

Will this one do fine: https://www.banggood.in/LILYGO-TTGO-T5-V2_4-Wifi-And-bluetooth-Basis-ESP-32-Esp32-1_54-or-2_13-or-2_9-EPaper-Diaplay-Module-Screen-Board-p-1691986.html

It's unclear which epaper display it uses. There is also this one (https://www.banggood.in/LILYGO-TTGO-T5-v2_4_1-ESP32-Bottom-Board-for-1_54-or-2_13-or-2_9-Inch-Electronic-ink-Screen-e-Paper-Module-p-1739701.html) without the display. Can I pair this esp32 with this screen (https://www.banggood.in/Waveshare-2_9-Inch-ink-Screen-Bare-Board-2_9inch-E-Ink-Display-HAT-296128-Resolution-Black-and-White-e-paper-Module-p-1753873.html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)

Thanks for your help in advance.

fliescher, 2023-08-16:
I'm also curious about the statement to use the Good Display E-Ink Display. What's the point for that? Any display that's supported by the official T5 Firmware should be working, right?
(Or at least should be possible to be used/implemented)

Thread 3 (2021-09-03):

Heading indication wouldn't work

jlMarsu, 2021-09-03:
Hello

I built the vario on TT w/ 2.9'' paperink screen
I did setup Hardware config etc .. and compiled successfully
GPS / Display work fine.
Pressure sensor works fine (detects successfully pressure increase / decrease => vario speed)
I only have an issue with heading indication which either is totally random, or is about stand still.
I have ran the calibration process, including online calibration file computing, but don't get any improvement.

Maybe did I miss some setup in hardwareconfig file, but I can't figure out which parameter .....

Would you have any suggestion about what I could do to improve the situation ?

I am running at the moment the test code ....

Thanks for any feedback

Great project indeed!

JL

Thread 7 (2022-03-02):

idea: Paramotor engine integration

mikechristiansen, 2022-03-02:
Hi Dev,
Thank you very much for sharing this project! I have just built one unit and have used it once but it is fantastic! Love the way your integrating modules making the build very straight forward.

Im just getting into paramotoring after free flying for many years. There are many RPM and cylinder head temperature (CHT) gauges available to monitor your engine in flight. Most are cobbled together from the scooter market and mostly seperate devices meaning you end up with wires and modules everywhere. Nothing affordable exists with data logging functions.
There are the high end systems like the IQ Motor+ https://naviter.com/brauniger-iq-motor/ however these seem to be end of line.

I wonder if its possible to build a device say using a ESP32 with BLE to measure these motor values and send them to your variometer to display and record? Im guessing this would require significant code changes on your variometer and seperate "engine module" hardware / code development.

if your interested in extending your project in this direction im keen to assist where I can. I could do some hardware development, minor software (limited skills here) and testing. Im hoping there are others that are also interested in this?

Kind regards and thank you for everything you have given us here.

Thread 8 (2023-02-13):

No beeping during calibration

herbertkatz, 2023-02-13:
Discovered a little bug today.
When the vario is set to be muted until start of the flight it is also muted during the calibration.

So to hear the buzzer during calibration you need to have 'Mute until start of flight' in the Webserver in 'Configuration' -> 'FLIGHT START' unchecked!
Or in the 'params.jso' write "MUTE_VARIOBEGIN":0

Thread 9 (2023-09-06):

display shivers

fliescher, 2023-09-06:
I just built a GNUVario-E with the PCB v2 and a TTGO-T5 v2.4 with a Display DEPG0150BN - so not the recommended Good Display Unit.
When the speaker is connected, the values on the e-ink display are starting in black but getting greyish, white and black randomly. It's not the whole number/letter getting darker or brighter but only tiny parts of each. When I cut the wire of the speaker, everything is working fine.

Has this problem be encountered with other Displays (the Good Display for example) as well?

finchm, 2024-12-02:
I believe you are describing the issue I had.  The screen starts dark and gets progressively lighter.  Commenting out the powerOff() call in the screenTask infinite loop fixed the issue for me.  Issue #12

LinkerHoden, 2024-12-03:
Thank you! That was the exact fix for the problem for me.

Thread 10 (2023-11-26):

i2c_t

repin, 2023-11-26:
An error appears when trying to compile the code
.../IntTW.h:156:3: error: 'i2c_t' does not name a type; did you mean 'ino_t'?
    i2c_t* i2c;
    ^~~~~
    ino_t
...\IntTW/IntTW.h:157:3: error: 'i2c_err_t' does not name a type; did you mean 'esp_err_t'?
    i2c_err_t volatile twError;
    ^~~~~~~~~
    esp_err_t

Can you tell me how to get through it?

finchm, 2024-12-02:
You have too new a version of the boards file.  Roll your esp32 board back to 1.0.4 and it will compile.

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

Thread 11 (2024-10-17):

Where is the code

aryanlovestech, 2024-10-17:
I don't see any file for the variometer code. Where can I get it from

davinderc, 2025-02-28:
You can follow the instructions here, but they are quite confusing especially with screenshots referring to a different repo: https://prunkdump.github.io/GNUVario-TTGO-T5-website-EN/code/recup_code.html

aryanlovestech, 2025-02-28:
@davinderc have you built one?

davinderc, 2025-02-28:
I'm trying to get the code to compile right now, hopefully I can get it working on my ESP32-C3 Super Mini, otherwise I'll have to see if I buy a different board

davinderc, 2025-02-28:
Also, there's a lot of missing (or difficult to find) information, such as which library versions to use, etc... I see a screenshot showing the board manager selecting ESP32 package version 1.0.4, but version 3+ is already out

aryanlovestech, 2025-02-28:
@davinderc if you are in bir paragliding group then ketan has made one

aryanlovestech, 2025-02-28:
@davinderc the barometer part is quite easy you just have to integrate the accelerometer and barometer code for imu. Rest gps and display is easy

davinderc, 2025-02-28:
Where is this group? At the moment I just want to have the barometer working with my ESP32 and a passive speaker, my new phone doesn't have a barometer.

Later I will build one with IMU, barometer, GPS and all the bells and whistles...

aryanlovestech, 2025-02-28:
@davinderc I had made one with only barometer and Arduino and it worked good. You should just convert the code to esp32. If you want code I'll give you the detail email me on trollbot73@gmail.com

davinderc, 2025-02-28:
I just successfully compiled for the first time, using esp32 package 1.0.6. There will be an issue of python not found in the path because Python 2 was still used back then, but if you google the error there is a bash command that replaces all python references in the esp32 package with python3.

Now I just need to figure out how to turn off all the extra stuff and leave just the barometer and buzzer... although it seems this repo wasn't built for that level of customizability...

the arduino-vario repo is much more customizable, but only for arduino boards (converting is not too easy, I would have to fix library references and a bunch of errors I don't understand), and I would prefer to stay with my esp32 because it has built-in bluetooth (to connect to XCTrack on my phone) and it's very compact.

aryanlovestech, 2025-03-01:
@davinderc if you are planning to add accelerometer and gps and other such things I would recommend using Gnu Vario code but if you are going to stick to basic barometer vario just extract the code from Hari in air. He has made the best barometer only variometer

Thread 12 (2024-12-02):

FIX:  Screen starts dark and gets progressively dimmer

finchm, 2024-12-02:
Short answer:
Comment out line 719 in varioscreenGxEPD_291b.cpp to fix the display dimming.
//display.epd2.powerOff();

Long Answer:

I built two of these.  I used two different model displays.  Both devices have the same bug.  The first display of a page is very dark, but every partial refresh of the screen causes it to get dimmer.

I am using displays that work with the following initializer and VARIOSCREEN_SIZE == 294:
GxEPD2_BW<GxEPD2_290_T94, GxEPD2_290_T94::HEIGHT> display(GxEPD2_290_T94(/*CS=5*/ SS, /*DC=*/ 17, /*RST=*/ 16, /*BUSY=*/ 4)); // DKEG0290BNS800F6 / QYEG0290BNS800F6C02

I went through the code and I found an issue in varioscreen/varioscreenGxEPD_291b.cpp

The function screenTask calls display.display(true) and then calls display.epd2.powerOff();

The call to powerOff() is what causes the screen to dim.  Removing this line fixes the issue.

Looking deeper into the display.display() call shows that it is implemented in GxEPD2/src/GxEPD2_BW.h.  This function DOES call powerOff() BUT only when a FULL update is done.

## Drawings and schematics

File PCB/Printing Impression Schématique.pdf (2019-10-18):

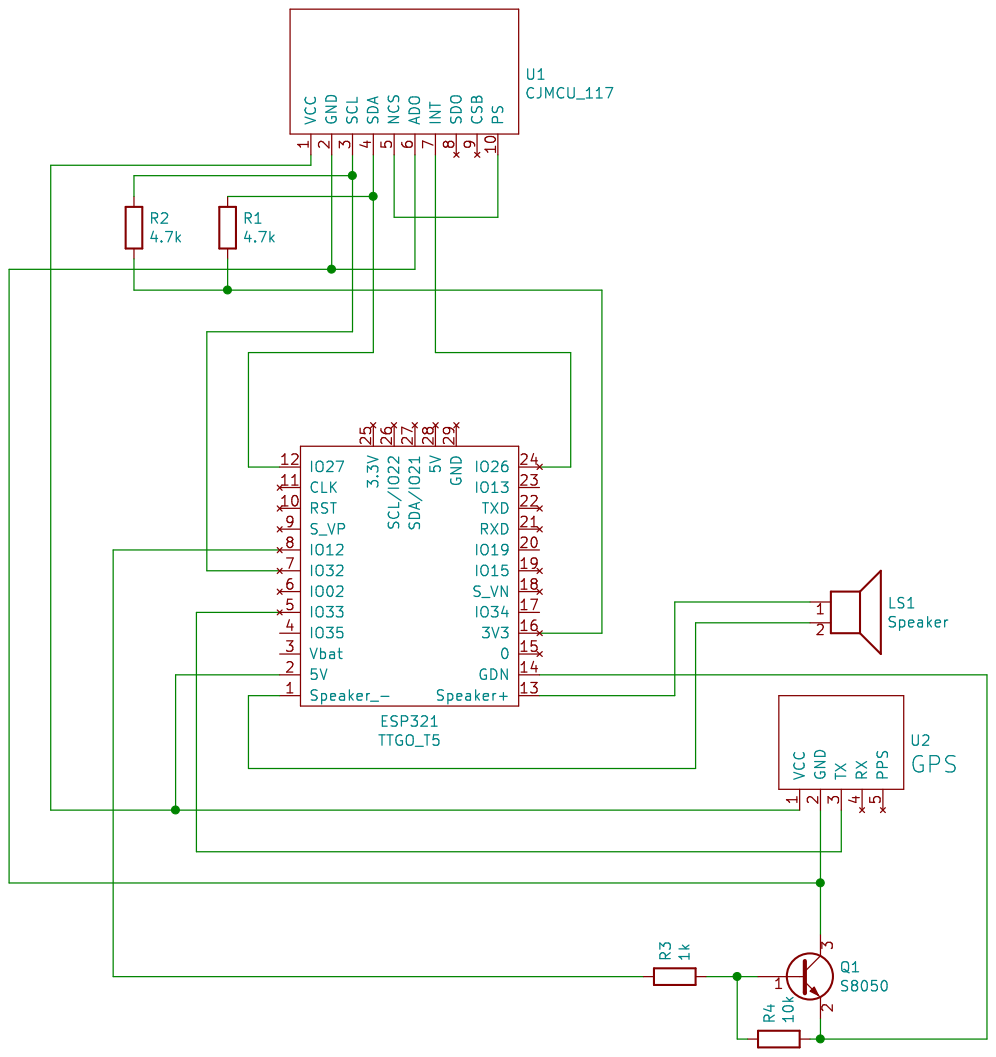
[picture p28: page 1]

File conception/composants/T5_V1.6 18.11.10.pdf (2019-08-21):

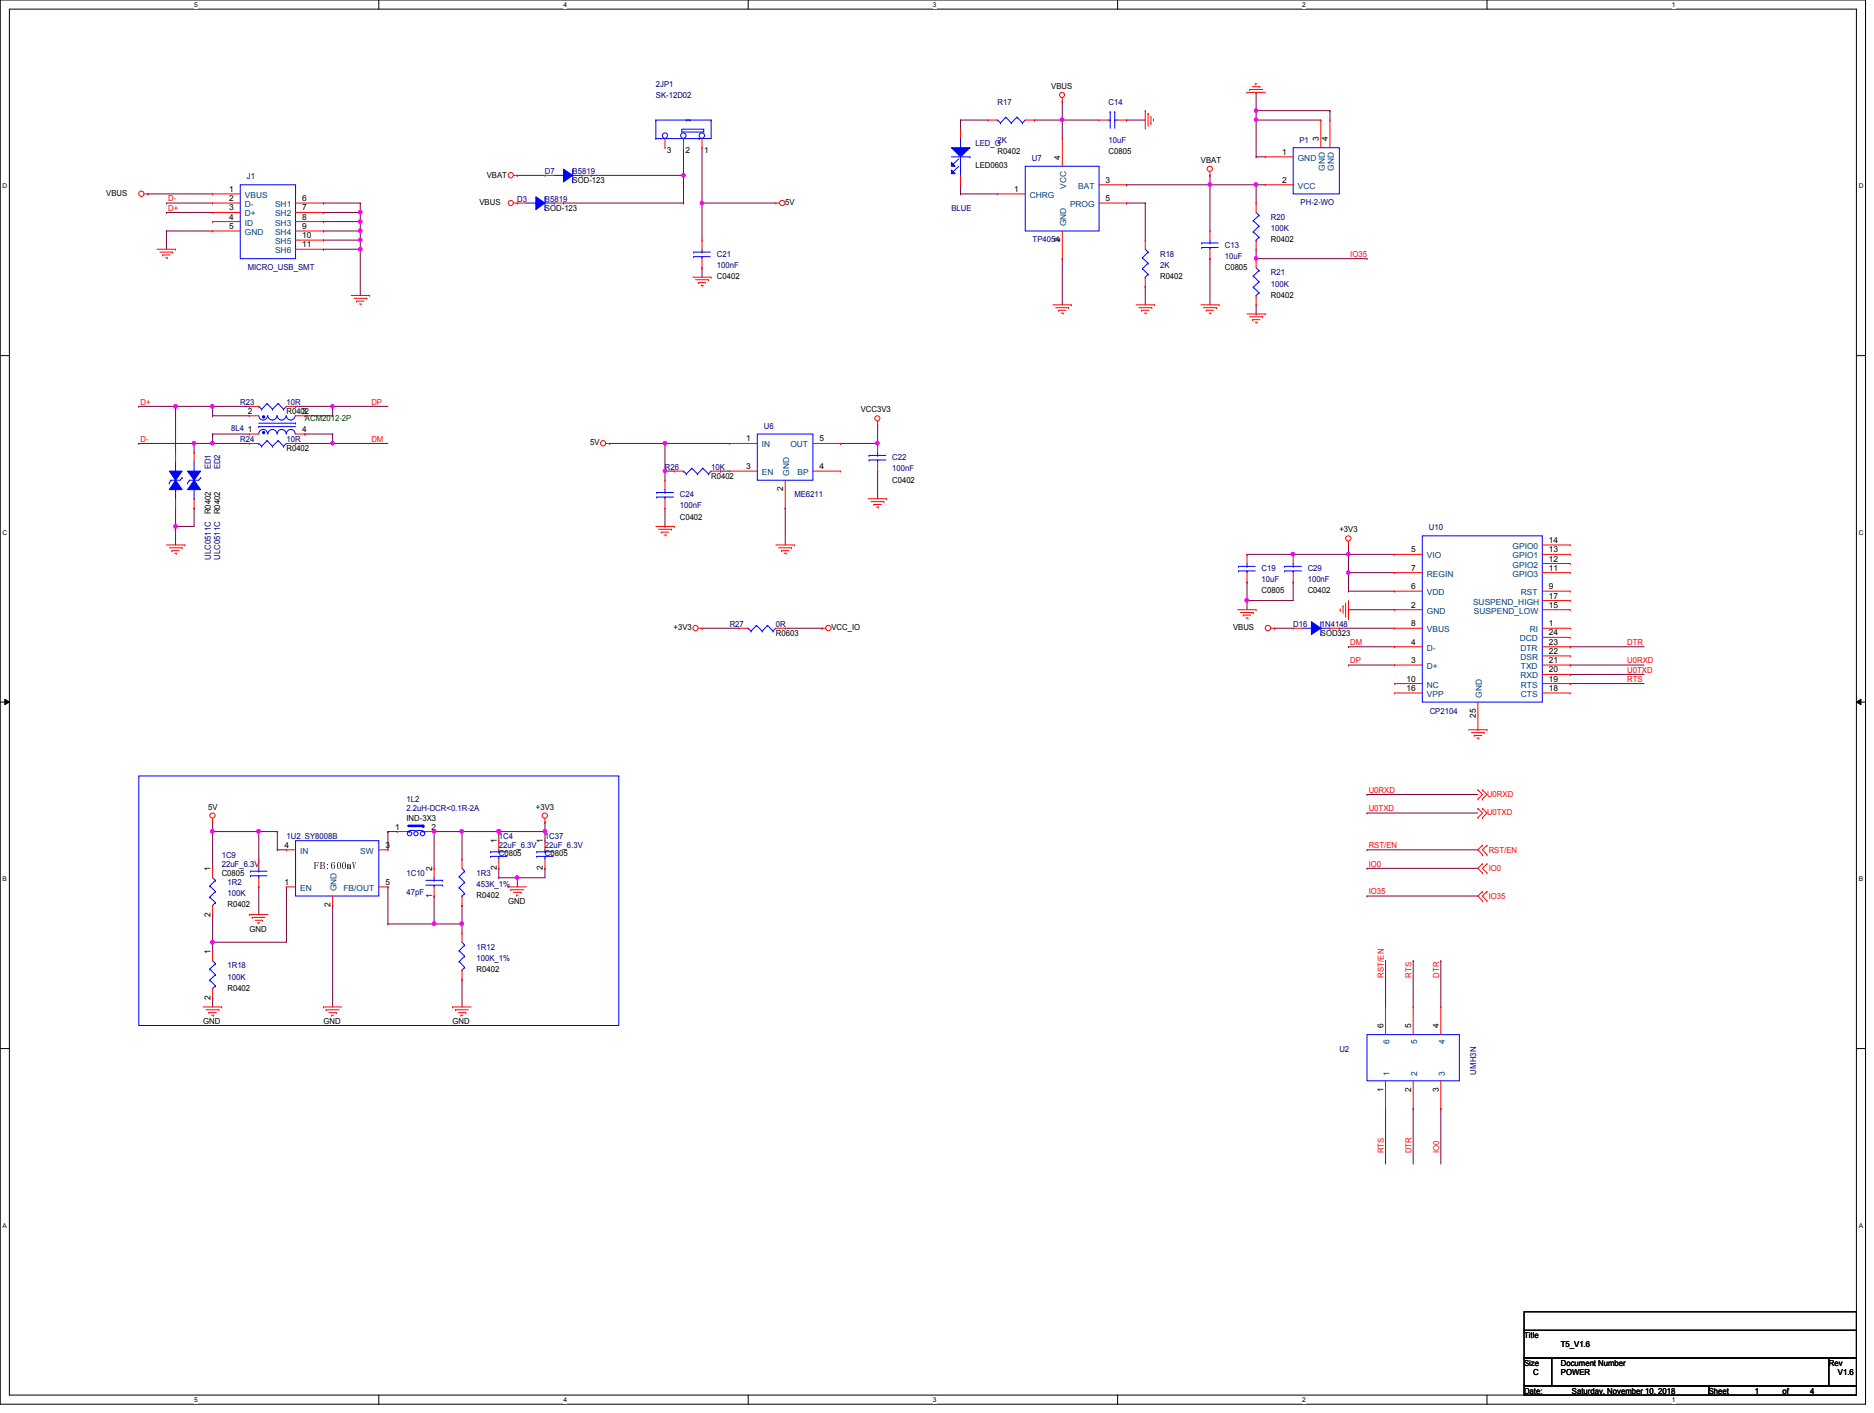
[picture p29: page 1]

D | D

# ED0/IO18

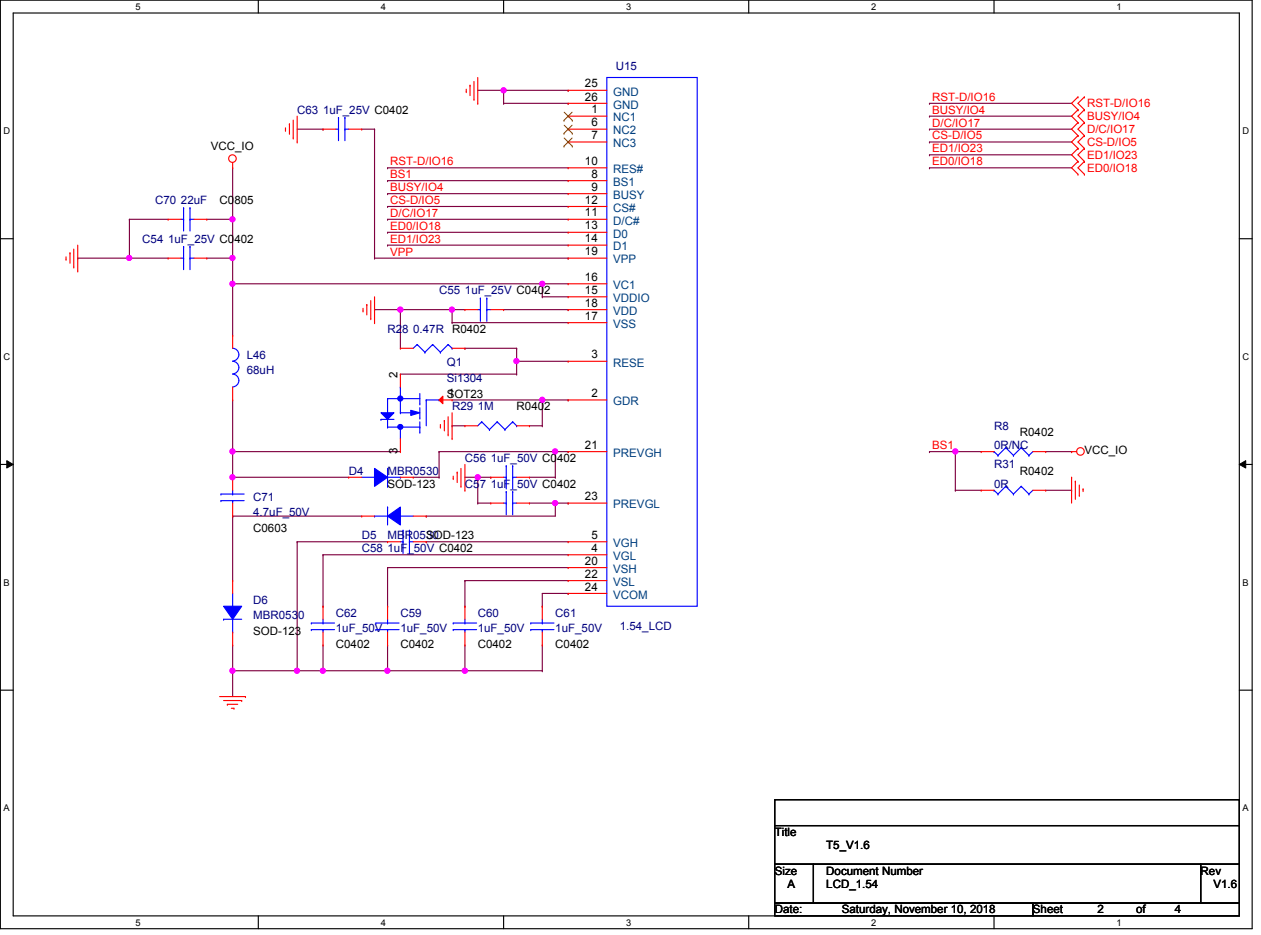
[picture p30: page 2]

D | D

# VCC3V3

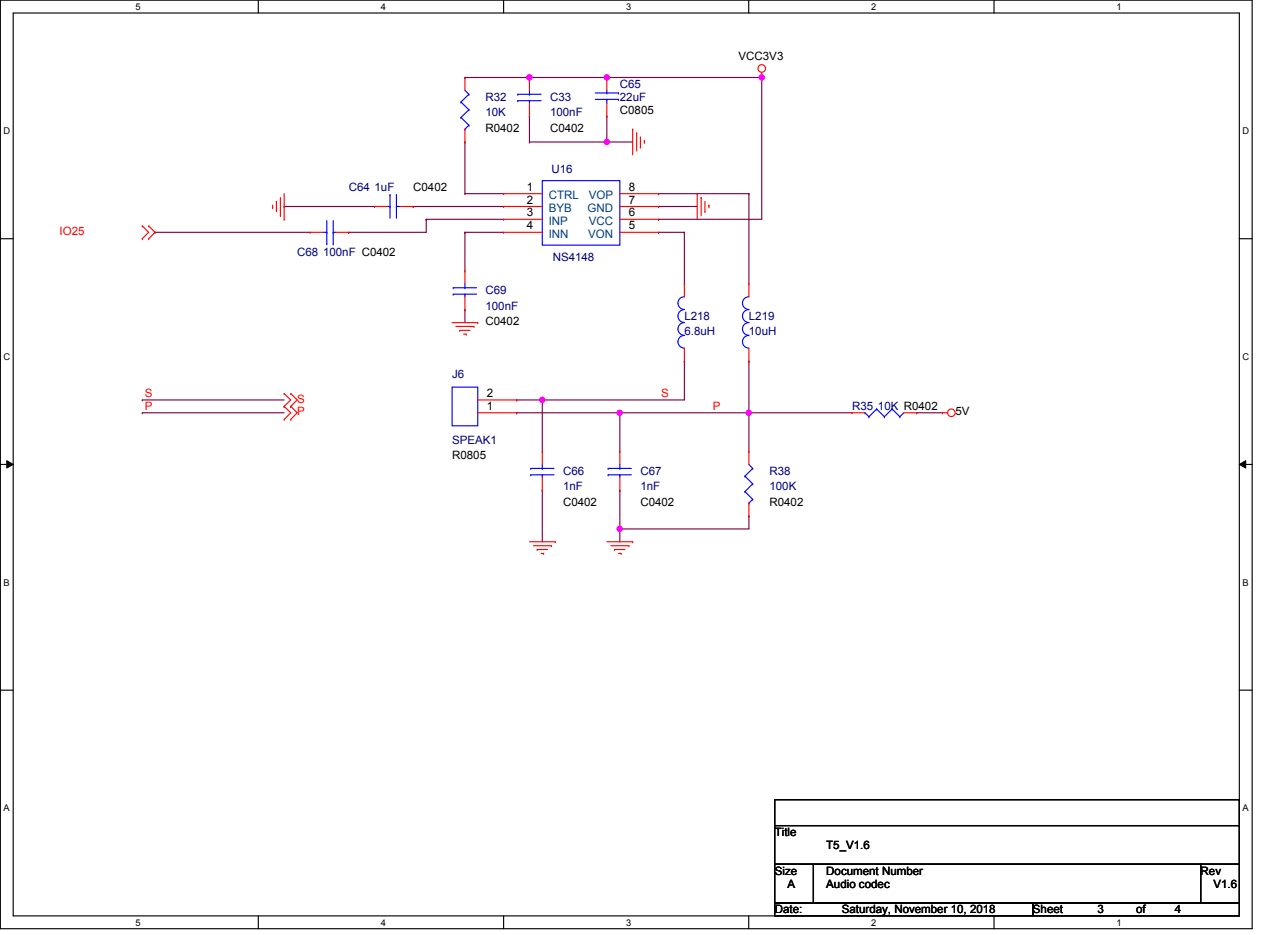
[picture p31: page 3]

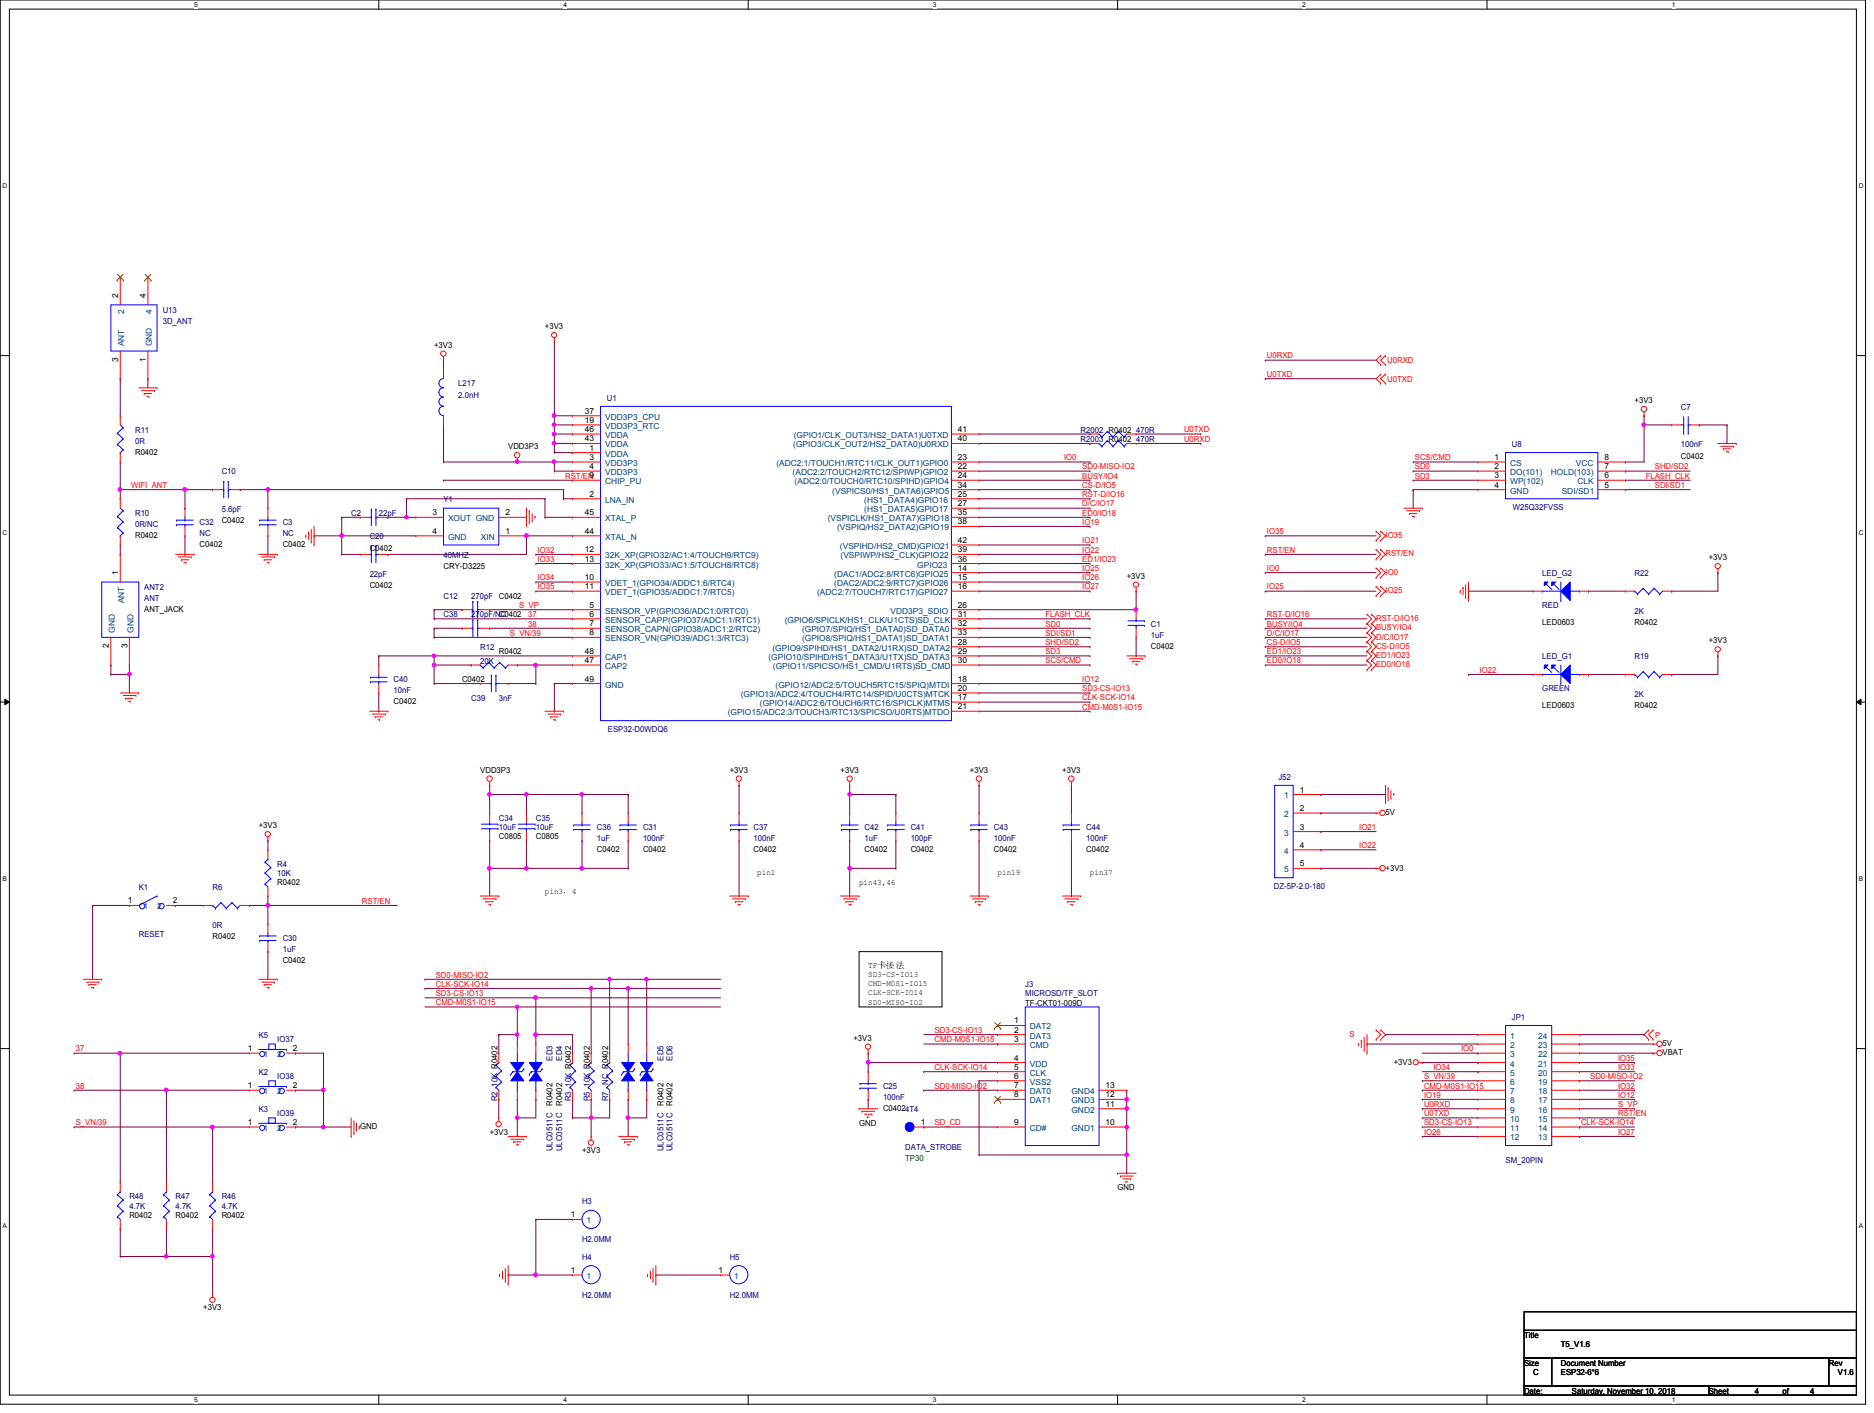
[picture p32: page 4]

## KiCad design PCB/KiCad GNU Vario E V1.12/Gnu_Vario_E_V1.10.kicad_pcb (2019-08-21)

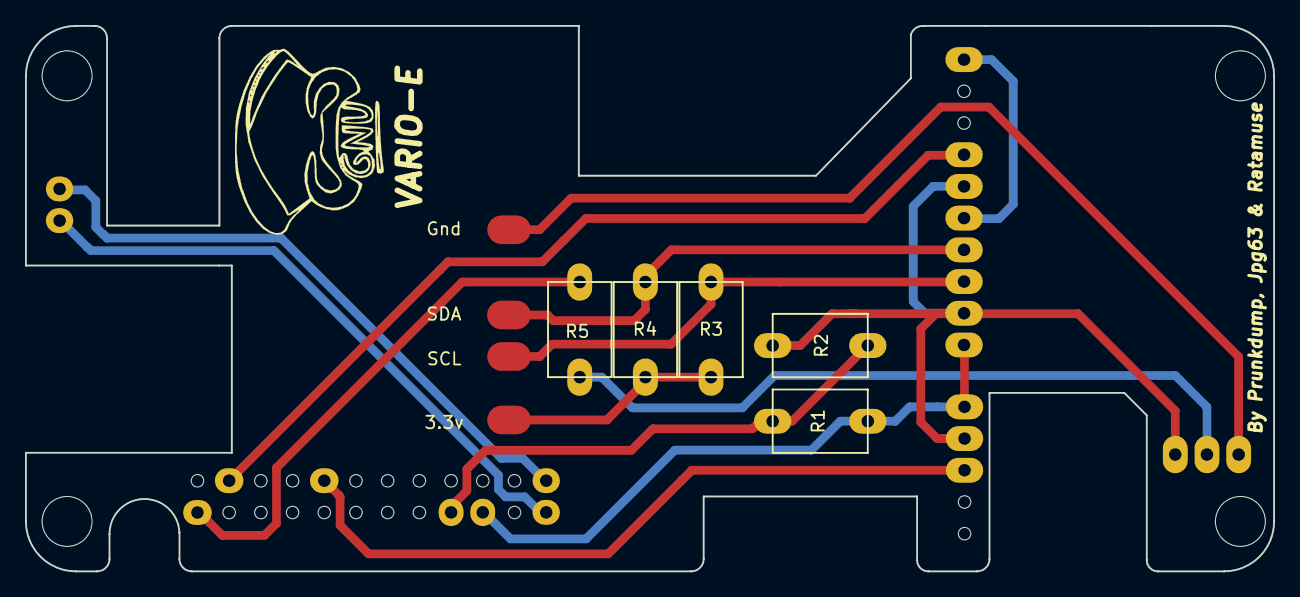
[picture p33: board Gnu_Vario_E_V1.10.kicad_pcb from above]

Board: 2 copper layers, 100.0 x 43.7 mm, 11 parts (0 on the bottom side), 14 nets.

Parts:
BCxxx1: S8050; Transistor
CJMCU_117: MPU-9250+MS5611; CJMCU-117
GPS1: ATGM336H; GPS
J1: Pads connection; Pads_connection
R1: 270k; R1
R2: 1M; R1
R3, R4: 4.7k; R1
R5: 1K; R1
Speaker1: 4-8 ohms; Speaker
TTGO_T5_V1.x1: NIL; TTGO_T5_V1.x

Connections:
unnamed: BCxxx1.1, J1.1
unnamed: BCxxx1.2, R5.2
unnamed: BCxxx1.3, CJMCU_117.2, CJMCU_117.6, GPS1.2, R2.1
unnamed: CJMCU_117.1, GPS1.1, R1.2, TTGO_T5_V1.x1.3
unnamed: CJMCU_117.3, J1.4, R3.1
unnamed: CJMCU_117.4, J1.3, R4.1
unnamed: CJMCU_117.7, TTGO_T5_V1.x1.23
unnamed: CJMCU_117.5, CJMCU_117.10
unnamed: GPS1.3, TTGO_T5_V1.x1.20
unnamed: J1.5, R3.2, R4.2
unnamed: R1.1, R2.2, TTGO_T5_V1.x1.4
unnamed: R5.1, TTGO_T5_V1.x1.12
unnamed: Speaker1.1, TTGO_T5_V1.x1.13
unnamed: Speaker1.2, TTGO_T5_V1.x1.1

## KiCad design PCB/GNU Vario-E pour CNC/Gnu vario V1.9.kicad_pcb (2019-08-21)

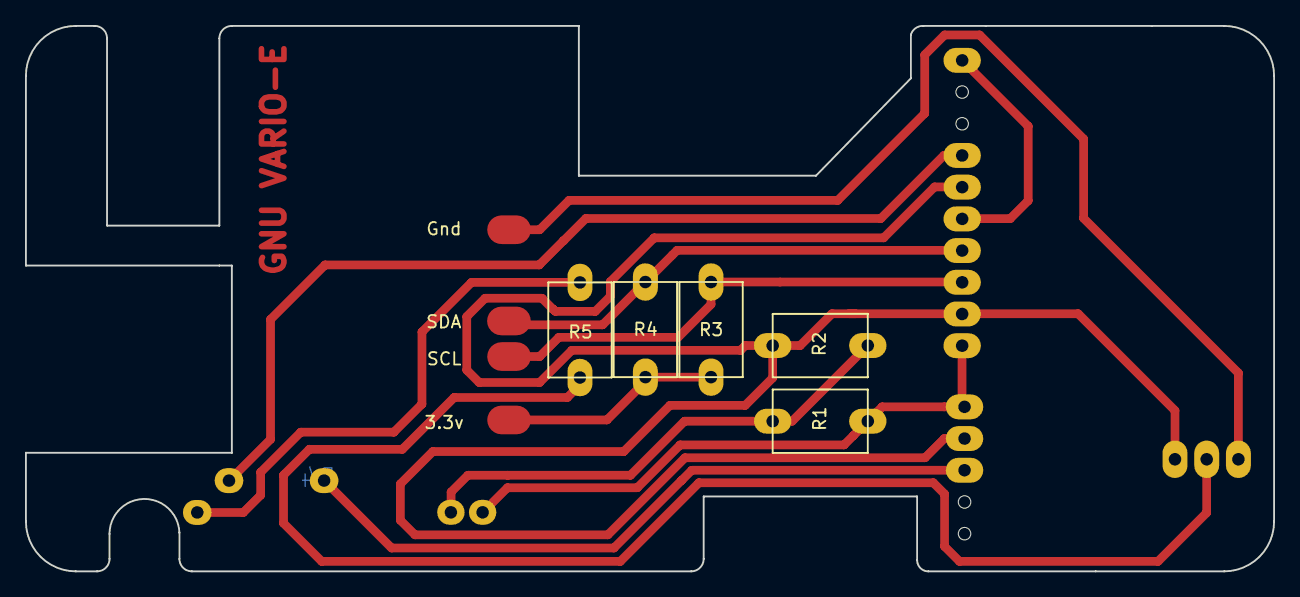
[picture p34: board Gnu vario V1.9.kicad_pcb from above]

Board: 2 copper layers, 100.0 x 43.7 mm, 10 parts (0 on the bottom side), 12 nets.

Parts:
BCxxx1: S8050; Transistor
J1: Conn_01x05; Pads_connection
R1: 270k; R1
R2: 1M; R1
R3, R4: 4.7k; R1
R5: 1K; R1
TTGO T5 V1.x: TTGO_T5; TTGO_T5_V1.09
U1: CJMCU_117; CJMCU-117
U2: ATGM336H; GPS

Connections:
unnamed: BCxxx1.1, J1.1
unnamed: BCxxx1.2, R5.2
unnamed: BCxxx1.3, R2.1, U1.2, U1.6, U2.2
unnamed: R1.2, TTGO T5 V1.x.3, U1.1, U2.1
unnamed: R1.1, R2.2, TTGO T5 V1.x.4
unnamed: R5.1, TTGO T5 V1.x.12
unnamed: TTGO T5 V1.x.20, U2.3
unnamed: TTGO T5 V1.x.23, U1.7
unnamed: J1.3, R4.1, U1.4
unnamed: J1.4, R3.1, U1.3
unnamed: J1.5, R3.2, R4.2
unnamed: U1.5, U1.10

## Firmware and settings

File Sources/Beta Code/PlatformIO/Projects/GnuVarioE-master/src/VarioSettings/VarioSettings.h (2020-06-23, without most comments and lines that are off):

#define _VARIO_SETTINGS_H_
#include <Arduino.h>
#include "DebugConfig.h"
#include <HardwareConfig.h>
#ifdef HAVE_SDCARD
#include <sdcardHAL.h>
#endif
#define PARAMS_VERSION "1.5"
#define DEFAULT_VARIOMETER_PILOT_NAME  										"Magali"
#define DEFAULT_VARIOMETER_GLIDER_NAME 										"MAC-PARA Muse 3"
#define DEFAULT_VARIOMETER_GLIDER_SELECT									0
#define DEFAULT_VARIOMETER_TIME_ZONE  										(+2)
#define DEFAULT_VARIOMETER_BASE_PAGE_DURATION 						3000
#define DEFAULT_VARIOMETER_MULTIDISPLAY_DURATION 			  	2000
#define DEFAULT_VARIOMETER_BEEP_VOLUME 										3
#define DEFAULT_VARIOMETER_SINKING_THRESHOLD 							-2.0
#define DEFAULT_VARIOMETER_CLIMBING_THRESHOLD							0.2
#define DEFAULT_VARIOMETER_NEAR_CLIMBING_SENSITIVITY			0.5
#define DEFAULT_VARIOMETER_ENABLE_NEAR_CLIMBING_ALARM   	false
#define DEFAULT_VARIOMETER_ENABLE_NEAR_CLIMBING_BEEP    	false
#define DEFAULT_FLIGHT_START_MIN_TIMESTAMP 								15000
#define DEFAULT_FLIGHT_START_VARIO_LOW_THRESHOLD 					(-0.5)
#define DEFAULT_FLIGHT_START_VARIO_HIGH_THRESHOLD 				0.5
#define DEFAULT_FLIGHT_START_MIN_SPEED 										8.0
#define DEFAULT_VARIOMETER_RECORD_WHEN_FLIGHT_START 			true
#define DEFAULT_ALARM_SDCARD 															true
#define DEFAULT_ALARM_GPSFIX 															true
#define DEFAULT_ALARM_FLYBEGIN 														true
#define DEFAULT_SETTINGS_CLIMB_PERIOD_COUNT  							10
#define DEFAULT_SETTINGS_GLIDE_RATIO_PERIOD_COUNT 				20
#define DEFAULT_VARIOMETER_DISPLAY_INTEGRATED_CLIMB_RATE	false
#define DEFAULT_RATIO_CLIMB_RATE 													1
#define DEFAULT_NO_RECORD 																false
#define DEFAULT_BATTERY_TONE_FREQHZ												400
#define DEFAULT_CALIB_TONE_FREQHZ													800
#define DEFAULT_MPU9250_ERROR_TONE_FREQHZ									200
#define DEFAULT_MS5611_ERROR_TONE_FREQHZ									2500
#define DEFAULT_SDCARD_ERROR_TONE_FREQHZ									2000
#define DEFAULT_BEEP_FREQ                  								800
#define LK8000_SENTENCE																		0
#define LXNAV_SENTENCE																		1
#define DEFAULT_VARIOMETER_SENT_LXNAV_SENTENCE						1
#define DEFAULT_BLUETOOTH_SEND_CALIBRATED_ALTITUDE        false
#define DEFAULT_VARIOMETER_SSID_1													"your_SSID1"
#define DEFAULT_VARIOMETER_PASSWORD_1											"your_PASSWORD_for SSID1"
#define DEFAULT_VARIOMETER_SSID_2													"your_SSID2"
#define DEFAULT_VARIOMETER_PASSWORD_2											"your_PASSWORD_for SSID2"
#define DEFAULT_VARIOMETER_SSID_3													"your_SSID3"
#define DEFAULT_VARIOMETER_PASSWORD_3											"your_PASSWORD_for SSID3"
#define DEFAULT_VARIOMETER_SSID_4													"your_SSID4"
#define DEFAULT_VARIOMETER_PASSWORD_4											"your_PASSWORD_for SSID4"
#define DEFAULT_URL_UPDATE 																"http://gnuvario-e.yj.fr/webupdate/checkversion"
#define DEFAULT_VERTACCEL_GYRO_CAL_BIAS_00								0x00
#define DEFAULT_VERTACCEL_GYRO_CAL_BIAS_01								0x00
#define DEFAULT_VERTACCEL_GYRO_CAL_BIAS_02								0x00
#define DEFAULT_VERTACCEL_GYRO_CAL_BIAS_03								0x00
#define DEFAULT_VERTACCEL_GYRO_CAL_BIAS_04								0x00
#define DEFAULT_VERTACCEL_GYRO_CAL_BIAS_05								0x00
#define DEFAULT_VERTACCEL_GYRO_CAL_BIAS_06								0x00
#define DEFAULT_VERTACCEL_GYRO_CAL_BIAS_07								0x00
#define DEFAULT_VERTACCEL_GYRO_CAL_BIAS_08								0x00
#define DEFAULT_VERTACCEL_GYRO_CAL_BIAS_09								0x00
#define DEFAULT_VERTACCEL_GYRO_CAL_BIAS_10								0x00
#define DEFAULT_VERTACCEL_GYRO_CAL_BIAS_11								0x00
#define DEFAULT_VERTACCEL_ACCEL_CAL_BIAS_00								0x00
#define DEFAULT_VERTACCEL_ACCEL_CAL_BIAS_01								0x00
#define DEFAULT_VERTACCEL_ACCEL_CAL_BIAS_02								0x00
#define DEFAULT_VERTACCEL_ACCEL_CAL_SCALE 								0
#define DEFAULT_VERTACCEL_MAG_CAL_BIAS_00									0
#define DEFAULT_VERTACCEL_MAG_CAL_BIAS_01									0
#define DEFAULT_VERTACCEL_MAG_CAL_BIAS_02									0
#define DEFAULT_VERTACCEL_MAG_CAL_PROJ_SCALE 							-16689
#define DEFAULT_VERTACCEL_ACCEL_CAL_BIAS_MULTIPLIER 			7
#define DEFAULT_VERTACCEL_MAG_CAL_BIAS_MULTIPLIER 				5
#define DEFAULT_RATIO_MAX_VALUE														30.0
#define DEFAULT_RATIO_MIN_SPEED														10.0
#define DEFAULT_VARIOMETER_ENABLE_BT										  0
#define DEFAULT_ALARM_VARIOBEGIN                          1
#define DEFAULT_COMPENSATION_TEMP													-6
#define DEFAULT_COMPENSATION_GPSALTI											-50
#define DEFAULT_SLEEP_TIMEOUT_MINUTES 										20
#define DEFAULT_SLEEP_THRESHOLD_CPS												0.5
#define DEFAULT_ALTERNATE_DATA_DURATION										2000
#define DEFAULT_DISPLAY_STAT_DURATION                     6
#define DEFAULT_VARIOMETER_ENABLE_AGL											true
#ifdef HAVE_ACCELEROMETER
#define DEFAULT_ACCELERATION_MEASURE_STANDARD_DEVIATION 	0.35   //0.30
#else
#define DEFAULT_ACCELERATION_MEASURE_STANDARD_DEVIATION 	0.6
#endif //HAVE_ACCELEROMETER
#define DEFAULT_LANGUAGE																	0
#define DEFAULT_VARIOMETER_INTEGRATED_CLIMB_RATE					false
#define DEFAULT_SETTINGS_VARIO_PERIOD_COUNT  							5
#define VARIOMETER_MODEL "GNUVario"
#define VARIOMETER_MODEL_NAME "GnuVario-E"
#define VARIOMETER_SPEED_FILTER_SIZE 5
#define POSITION_MEASURE_STANDARD_DEVIATION 0.1
#define SCREEN_MODEL_154 "154"
#define SCREEN_MODEL_290 "290"
#define SCREEN_MODEL_213 "213"
class VarioSettings {
 public:
  boolean initSettings(bool initSD);
#ifdef HAVE_SDCARD
  boolean readSDSettings(char *FileName, boolean *ModifiedValue);
  boolean readFlashSDSettings();
  void writeFlashSDSettings();
	void loadConfigurationVario(char *filename);
	void saveConfigurationVario(char *filename);
	void writeWifiSDSettings(char *filename);
	void setVersion(uint8_t version, uint8_t subVersion, uint8_t betaVersion);
	String getVersion(void);
	String getScreenModel(void);
#endif
  uint8_t soundSettingRead(void);
  void soundSettingWrite(uint8_t volume);
#ifdef SDCARD_DEBUG
  int exINT = 15;
  float exFloat = 1.12345;
  boolean exBoolean = true;
  long exLong = 2123456789;
#endif //SDCARD_DEBUG
  String VARIOMETER_PILOT_NAME 	= DEFAULT_VARIOMETER_PILOT_NAME;
	String VARIOMETER_GLIDER_TAB[4] = {DEFAULT_VARIOMETER_GLIDER_NAME, "", "", ""};
	uint8_t VARIOMETER_GLIDER_SELECT = DEFAULT_VARIOMETER_GLIDER_SELECT;
  String VARIOMETER_GLIDER_NAME = DEFAULT_VARIOMETER_GLIDER_NAME;
  int8_t VARIOMETER_TIME_ZONE 	= DEFAULT_VARIOMETER_TIME_ZONE;
  int16_t VARIOMETER_BASE_PAGE_DURATION 				= DEFAULT_VARIOMETER_BASE_PAGE_DURATION;
	int16_t VARIOMETER_MULTIDISPLAY_DURATION 			= DEFAULT_VARIOMETER_MULTIDISPLAY_DURATION;
  uint8_t VARIOMETER_BEEP_VOLUME								= DEFAULT_VARIOMETER_BEEP_VOLUME;
  float VARIOMETER_SINKING_THRESHOLD 						= DEFAULT_VARIOMETER_SINKING_THRESHOLD;
  float VARIOMETER_CLIMBING_THRESHOLD						=	DEFAULT_VARIOMETER_CLIMBING_THRESHOLD;
  float VARIOMETER_NEAR_CLIMBING_SENSITIVITY		= DEFAULT_VARIOMETER_NEAR_CLIMBING_SENSITIVITY;
  boolean VARIOMETER_ENABLE_NEAR_CLIMBING_ALARM = DEFAULT_VARIOMETER_ENABLE_NEAR_CLIMBING_ALARM;
  boolean VARIOMETER_ENABLE_NEAR_CLIMBING_BEEP  = DEFAULT_VARIOMETER_ENABLE_NEAR_CLIMBING_BEEP;
  long FLIGHT_START_MIN_TIMESTAMP 							= DEFAULT_FLIGHT_START_MIN_TIMESTAMP;
  float FLIGHT_START_VARIO_LOW_THRESHOLD 				= DEFAULT_FLIGHT_START_VARIO_LOW_THRESHOLD;
  float FLIGHT_START_VARIO_HIGH_THRESHOLD 			= DEFAULT_FLIGHT_START_VARIO_HIGH_THRESHOLD;
  float FLIGHT_START_MIN_SPEED 									= DEFAULT_FLIGHT_START_MIN_SPEED;
  boolean VARIOMETER_RECORD_WHEN_FLIGHT_START 	= DEFAULT_VARIOMETER_RECORD_WHEN_FLIGHT_START;
  int VARIOMETER_SENT_LXNAV_SENTENCE 			      	= DEFAULT_VARIOMETER_SENT_LXNAV_SENTENCE;
	bool BLUETOOTH_SEND_CALIBRATED_ALTITUDE         = DEFAULT_BLUETOOTH_SEND_CALIBRATED_ALTITUDE;
  boolean ALARM_SDCARD 														= DEFAULT_ALARM_SDCARD;
  boolean ALARM_GPSFIX 														= DEFAULT_ALARM_GPSFIX;
  boolean ALARM_FLYBEGIN 													= DEFAULT_ALARM_FLYBEGIN;
	boolean ALARM_VARIOBEGIN    										= DEFAULT_ALARM_VARIOBEGIN;
  float KF_ZMEAS_VARIANCE  			=   400.0f;
  float KF_ZACCEL_VARIANCE 			=   1000.0f;
  float KF_ACCELBIAS_VARIANCE   = 	1.0f;
   uint8_t CLIMB_THRESHOLD   			=   50;
   int8_t ZERO_THRESHOLD	 				=    5;
   int16_t SINK_THRESHOLD    			=   -250;
    uint16_t VARIO_MAX_FREQHZ   	=   4000;
    uint16_t VARIO_XOVER_FREQHZ 	=   2000;
    uint16_t VARIO_MIN_FREQHZ   	=   200;
    uint16_t VARIO_SINK_FREQHZ  	=   400;
    uint16_t VARIO_TICK_FREQHZ  	=   200;
		float 	 RATIO_MAX_VALUE 			=		DEFAULT_RATIO_MAX_VALUE;
		float		 RATIO_MIN_SPEED 			=		DEFAULT_RATIO_MIN_SPEED;
    double ACCELCALX = 0.0;
		double ACCELCALY = 0.0;
		double ACCELCALZ = 0.0;
    uint16_t BATTERY_TONE_FREQHZ												=	DEFAULT_BATTERY_TONE_FREQHZ;
    uint16_t CALIB_TONE_FREQHZ													=	DEFAULT_CALIB_TONE_FREQHZ;
    uint16_t MPU9250_ERROR_TONE_FREQHZ									= DEFAULT_MPU9250_ERROR_TONE_FREQHZ;
    uint16_t MS5611_ERROR_TONE_FREQHZ										= DEFAULT_MS5611_ERROR_TONE_FREQHZ;
    uint16_t SDCARD_ERROR_TONE_FREQHZ										= DEFAULT_SDCARD_ERROR_TONE_FREQHZ;
		uint16_t BEEP_FREQ                  								= DEFAULT_BEEP_FREQ ;
		int8_t SETTINGS_CLIMB_PERIOD_COUNT  								= DEFAULT_SETTINGS_CLIMB_PERIOD_COUNT;
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

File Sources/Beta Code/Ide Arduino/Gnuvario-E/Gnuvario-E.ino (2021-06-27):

#include <Arduino.h>
#include <Adafruit_I2CDevice.h>

/*******************/
/* Version         */
/*******************/

#define VERSION 0
#define SUB_VERSION 8
#define BETA_CODE 6
#define DEVNAME "JPG63/MICELPA/RATAMUSE"
#define AUTHOR "J" //J=JPG63  P=PUNKDUMP  M=MICHELPA    R=RATAMUSE

/******************************************************************************************************/
/*                                              VERSION                                               */
/*                                               ESP32                                                */
/*                                       Optimisé pour TTGO-T5                                        */
/*                                                                                                    */
/*                                              Historique                                            */
/******************************************************************************************************/
/* v 0.1                             beta 1 version                                                   *
*  v 0.2     beta 1      23/06/19    debug VarioScreen                                                *      
*  v 0.3     beta 1      25/06/19    correction mesure tension                                        *
*                                    correction mesure de vitesse                                     *
*  v 0.3     beta 2      26/06/19    correction save IGC                                              *                                 
*  v 0.4     beta 1      03/07/19    ajout la coupure du son                                          *
*  v 0.4     beta 2      06/07/19    ajout statistique                                                *
*  v 0.4     beta 3      18/07/19    Correction gestion Eeprom                                        *
*                                    Correction tache affichage                                       * 
*                                    Ajout delete task display                                        *
*                                    Correction affichage statistique                                 *
* v 0.4      beta 4      22/07/19    Correction effacement screendigit                                *                             
*                                    Correction affichage duree du vol                                *
*                                    Correction affichage statistique                                 *
*                                    Modification FlightHistory                                       *
*                                    Ajout parametre flighthistory dans SETTINGS.TXT                  *
*                                    Enregistrement des statistique toutes les 60sec - reduction des  *
*                                    cycle d'ecriture dans la mémoire flash de l'ESP32                *
* v 0.4     beta 5    24/07/19       Ajout TrendDigit                                                 *
*                                    Modification TrendLevel                                          *
*                                    Modification screendigit                                         *
*                                    Correction démarrage du vol                                      *
*                                    indicateur de monte/descente                                     *
* v 0.4     beta 6    25/07/19       Ajout NO_RECORD                                                  *                                                                      
*                                    Correction TWOWIRESCHEDULER                                      *
* v 0.4     beta 7    05/08/19       Désactivation enregistrement stat pour eviter le bug du plantage * 
*                                    Ajout paramettre wifi                                            *
*                                    Modification SETTINGS.TXT v1.2                                   *
* v 0.4     beta 8    06/08/19       Ajout icone Norecord                                             *
*                                    Correction bug statistique                                       *
*                                    Raffraichissement de l'ensemle de l'écran toutes les 30sec       *
* v 0.5     beta 1    10/08/19       Ajout Gestionnaire d'erreur ESP32                                *
*                                    Mise à jour via SDCARD /update.bin                               *
*                                    Ajout Serveur Web update/download                                *
*                                    Ajout HAVE_WIFI                                                  *
*                                    Ajout BT                                                         *
* v 0.5     beta 2    20/08/19       Ajout dans hardwareConfig32 de la  version du PCB et de la TTGO  *
*                                    Ajout lecture de la temperature                                  *
*                                    MAJ OTA Web serveur                                              *
*                                    Ajout changement de page                                         *
*                                    Ajout 2ème ecran                                                 *
* v 0.5     beta 3  25/08/19         Ajout LOW/HIGH level cmd ampli                                   *
*                                    Ajout ecran reglage volume du son                                *
*                                    Correction Bug bouton                                            *
* v 0.5     beta 4  28/08/19         Ajout écran stat                                                 *                                   
*                                    Modification librairie ToneHAL                                   *
*                                    Correction bug d'affichage mineurs                               *
* v 0.5     beta 5  31/08/19         Correction bg reglage volume                                     *
*                                    Ajout commande ampli dans loop pour test                         *
* v 0.5     beta 6  04/09/19         Changement librairies MS5611 et MPU9250                          *                                   
*                                    Modifié la calibration de l'altitude par le GPS                  *
*                                    Ajout d'un coeficiant de compensation de temperature             *
*                                    Modification la séquence de démarrage de l'enregistrement        *
* v 0.5     beta 7  10/09/19         Ajout de SDA_Pin et SCL_Pin                                      *                                                                 
*                                    Modification des librairies du MPU9250 / ajout fonctions de      *                                                                             
*                                    Calibration                                                      *
*                                    Modification de la sequence de démarrage -                       *
*                                    allongement du temps de l'écran de stat à 6 sec                  *
*                                    init MS5611 avant ecran stat, ajout acquisition durant ecran     *
*                                    stat et init kalman après                                        *
*                                    Ajout d'un paramettre de nombre d'acquisition du GPS avant       * 
*                                    la mise à jour de Altitude Barametrique                          *
*                                    Modification librairie EEPROM                                    *
*                                    Ajout de la lecture de l'alti baro durant l'attente de l'écran   *
*                                    de stat                                                          *
* v 0.5   beta 8  22/09/19           Modification de l'affichage de Vbat                              *
*                                    Ajout d'un filtrage de la mesure de Vbat                         *
*                                    Ajout deep_sleep en cas de batterie trop faible                  *
* v 0.5   beta 9  23/09/19           Correction affichage ecran Stat                                  *                                    
*                                    Ajout possibilité d'avoir plusieurs tailles d'écran              *
*                                    Deep-sleep sur bouton central (3 sec)                            *
* v 0.6   beta 1  26/09/19           Ajout mise en sommeil                                            *                                   
*                                    Flash via USB en utilisant flash_download_tools                  *
*                                    Ajout ecran calibration                                          *
*                                    Modification SETTING.TXT (Version 1.3)                           *
*                                    Correction HAVE_SDCARD                                           *
*                                    Changement de la librairie webserver                             *
* v 0.6   beta 2  06/10/19           Ajout varioscreen pour l'écran 2.9''                             *
*                                    Ajout serveur Web sur sdcard                                     *
*                                    Correction du bug d'affichage des fleches                        *
*                                    Ajout du nom des champs de données sur l'écran                   *
*                                    Couper le SSID à 12 caractères                                   *                     
*                                    Modification du fichier SETTINGS.TXT v1.4                        *                                                                                                    
*                                    Ajout paramettre d'activation du BT dans le fichier SETTINGS.TXT *
*                                    Modification de varioscreen pour gérer les lignes et les cercles *
*                                    ainsi que les titres des champs de donnée                        *
*                                    Modification de l'arborescence de la carte SD                    *           
*                                    Enregistrement des fichiers .IGC (traces) dans le dossier 'vols' *
*                                    Mise à jour Ecran 2,9''                                          *
*                                    Modifier l'affichage des titres pour que la position             *
*                                    soit liée au digit                                               *
* v 0.6   beta 3  20/10/19           Correction bug enregistrement sur la SD                          *
*                                    recodage de l'affichage des satellites                           *       
*                                    Ajout desactivation bip au demarrage                             * 
*                                    Ajout écran 2.13''                                               *
*                                    Ajout compensation de température et correction altitude GPS     *
*                                    dans le fichier SETTINGS.TXT                                     *
* v 0.6   beta 4  27/10/19           Correction gestion zone horaire                                  *
*                                    Changement de librairie MS5611 et MPU                            *
*                                    Ajout compensation alti gps                                      *
*                                    Ajout d'un bip lors du reglage du volume                         *
*                                    Amélioration gestion des boutons et des écrans au boot           *
*                                    Correction gestion du volume                                     *
*                                    Correction Calibration enableAmp                                 *
*                                    Correction du bug d'affichage de l'écran de stat                 *
*                                    Correction du bug de reboot / blocage si #define DEBUG_PRO est   *      
*                                    commenté                                                         *
* v 0.6  beta 5 03/11/19             Déplacement validation deep-sleep sur bouton gauche              *
*                                    Corrections mineures sur varioscreen 2.9''                       *
*                                    Corrections mineures sur varioscreen 1.54''                      *  
*                                    Amélioration de la gestion de la première mesure d'altitude      *
*                                    Correction du bug de l'écran qui fige                            *
*                                    Moyenne alti Gps sur 15 mesures avant calibration baro           *
* v 0.6  beta 6 11/11/19             plusieurs fichiers de configurations / params.jso                *
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
void loop()
{
  SerialPort.println("loop");
  //****************************
  //****************************

  //****************************
  // Gestion Des chrono
  //***************************

  /*  LOW UPDATE DISPLAY */
  if (millis() - varioData.lastDisplayTimestamp > DISPLAY_LOW_UPDATE)
  {
    varioData.lastDisplayTimestamp = millis();
    varioData.displayLowUpdateState = true;
  }

  // DISPLAY
  if (millis() - varioData.lastDisplayTimestamp2 > DISPLAY_UPDATE)
  {
    varioData.lastDisplayTimestamp2 = millis();
    varioData.displayUpdateState = true;
  }

  //**********************************************************
  //  TRAITEMENT DU SON
  //**********************************************************

  toneHAL.update();

  //**********************************************************
  //  TRAITEMENT DES BOUTONS
  //**********************************************************

  ButtonScheduleur.update();

  //**********************************************************
  //  ACQUISITION DES DONNEES
  //**********************************************************

  varioData.update();

  //**********************************************************
  //  TEST INNACTIVITE
  //**********************************************************
  varioHardwareManager.testInactivity(varioData.getVelocity());

  //**********************************************************
  //  MISE A JOUR DE L'ECRAN
  //**********************************************************

  if (varioData.displayLowUpdateState)
  {

    //**********************************************************
    //  DISPLAY ALTI
    //**********************************************************

    screen.altiDigit->setValue(varioData.getCalibratedAlti());

    //**********************************************************
    //  DISPLAY VARIO
    //**********************************************************

    if (GnuSettings.VARIOMETER_DISPLAY_INTEGRATED_CLIMB_RATE)
    {
      if (varioData.haveNewClimbRate())
      {
/*        double tmpvalue = varioData.getClimbRate();
#if (VARIOSCREEN_SIZE == 154)
        if (tmpvalue > 9.9)
          tmpvalue = 9.9;
        if (tmpvalue < -9.9)
          tmpvalue = -9.9;
#else
        if (tmpvalue > 99.9)
          tmpvalue = 99.9;
        if (tmpvalue < -99.9)
          tmpvalue = -99.9;
#endif
        screen.varioDigit->setValue(tmpvalue);*/

        screen.varioDigit->setValue(varioData.getClimbRate());
      }
    }
    else
    {

/*      double tmpvalue = varioData.getVelocity();
#if (VARIOSCREEN_SIZE == 154)
      if (tmpvalue > 9.9)
        tmpvalue = 9.9;
      if (tmpvalue < -9.9)
        tmpvalue = -9.9;
#else
      if (tmpvalue > 99.9)
        tmpvalue = 99.9;
      if (tmpvalue < -99.9)
        tmpvalue = -99.9;
#endif
      screen.varioDigit->setValue(tmpvalue);*/

      screen.varioDigit->setValue(varioData.getVelocity());
    }

    //**********************************************************
    //  DISPLAY FINESSE / TAUX DE CHUTE MOYEN
    //**********************************************************

    if (varioData.haveNewClimbRate())
    {
      if (GnuSettings.RATIO_CLIMB_RATE > 1)
        screen.trendDigit->setValue(varioData.getTrend());
      else
        screen.trendDigit->setValue(0);
      screen.trendLevel->stateTREND(varioData.getStateTrend());
    }
    screen.trendDigit->reset();
  }

  //**********************************************************
  //  EMISSION DES BIPS
  //**********************************************************

  /*****************/
  /* update beeper */
  /*****************/
#ifdef HAVE_SPEAKER
  beeper.update();
#ifdef PROG_DEBUG
//    SerialPort.println("beeper update");
#endif //PROG_DEBUG
#endif //HAVE_SPEAKER

  //**********************************************************
  //  TRAITEMENT DU SON
  //**********************************************************

  //***************************************
  //  TEST
  //***************************************
#if defined(TONEXTDAC) || defined(TONEI2S) 
  toneHAL.update();
#endif

  //**********************************************************
  //  EMISSION TRAME BT
  //  ACQUISITION GPS
  //**********************************************************

#ifdef HAVE_GPS
  //avec gps le bluetooth est mis a jour en meme temps que la trame gps
  /**************/
  /* update GPS */
  /**************/

  varioData.updateGps();

  //**********************************************************
  //  DETECTION FIX GPS / DEBUT DU VOL
  //**********************************************************

  varioData.updateState();
#else //HAVE_GPS

//sans gps, le bluetooth doit etre mis a jour manuellement
#ifdef VARIOMETER_BLUETOOTH_SEND_CALIBRATED_ALTITUDE
  varioHardwareManager.varioBle->bluetoothNMEA.begin(varioData.kalmanvert.getCalibratedPosition(), varioData.kalmanvert.getVelocity());
#else
  varioHardwareManager.varioBle->bluetoothNMEA.begin(varioData.kalmanvert.getPosition(), varioData.kalmanvert.getVelocity());
#endif

  // * if no GPS, we can't calibrate, and we have juste to check flight start */

  //**********************************************************
  //  DETECTION FIX GPS / DEBUT DU VOL
  //**********************************************************

  varioData.updateState();

#endif //HAVE_GPS

  /********************/
  /* update Bluetooth */
  /********************/

#if defined(HAVE_BLUETOOTH)
  if (varioData.updateBluetooth())
  {
#ifdef GPS_DEBUG
    SerialPort.println("Update BLE");
#endif //GPS_DEBUG
  }
#endif // HAVE_BLUETOOTH 

#ifdef HAVE_SCREEN
  if ((varioData.gpsFix > 0) && (varioData.gpsFix < 3))
    screen.recordIndicator->setActifGPSFIX();
  if (varioData.gpsFix == 2)
    screen.fixgpsinfo->setFixGps();

#endif //HAVE_SCREEN

    ////////////////////////////////////

    /**********************************/
    /* update low freq screen objects */
    /**********************************/
#ifdef HAVE_SCREEN

    //**********************************************************
    //  DISPLAY TIME / DUREE DU VOL
    //**********************************************************

    /************************************/
    /* Update Time, duration            */
    /* Voltage, SatLevel                */
    /************************************/

#ifdef HAVE_GPS

  if (varioData.displayLowUpdateState)
  {
    if (nmeaParser.haveDate())
    {

      /* set time */
#if defined(GPS_DEBUG) || defined(DATA_DEBUG)
      SerialPort.print("Time : ");
      SerialPort.println(nmeaParser.time);
#endif //GPS_DEBUG

      //      DUMPLOG(LOG_TYPE_DEBUG,GPS_DEBUG_LOG,nmeaParser.time);

      screen.screenTime->setTime(nmeaParser.time);
      screen.screenTime->correctTimeZone(GnuSettings.VARIOMETER_TIME_ZONE);
      if (varioData.getVariometerState() == VARIOMETER_STATE_FLIGHT_STARTED)
      {
        screen.screenElapsedTime->setCurrentTime(screen.screenTime->getTime());
        varioData.flystat.SetTime(screen.screenTime->getTime());
        varioData.flystat.SetDuration(screen.screenElapsedTime->getTime());
      }
      else
      {
        screen.screenElapsedTime->setCurrentTime(screen.screenTime->getTime());
      }
    }

    /* update satelite count */
    screen.satLevel->setSatelliteCount(nmeaParser.satelliteCount);
#ifdef GPS_DEBUG
    SerialPort.print("Sat : ");
    SerialPort.println(nmeaParser.satelliteCount);
#endif //GPS_DEBUG 
       //    DUMPLOG(LOG_TYPE_DEBUG,GPS_DEBUG_LOG,nmeaParser.satelliteCount);
  }
#endif //HAVE_GPS

  /*****************/
  /* update screen */
  /*****************/

  //**********************************************************
  //  DISPLAY SPEED
  //**********************************************************

#ifdef HAVE_GPS

  if (varioData.updateSpeed())
  {
    screen.speedDigit->setValue(varioData.getSpeed()); //currentSpeed);
    screen.ratioDigit->setValue(varioData.ratio);
  }
  else
  {
    screen.ratioDigit->setValue(0);
  }

  screen.ratioDigit->reset();

#endif //HAVE_GPS

  //**********************************************************
  //   DISPLAY LOW FRECQUENCE OBJECT
  //**********************************************************

  if (varioData.displayLowUpdateState)
  {

    //**********************************************************
    //  ACQUISITION / DISPLAY TENSION BATTERIE
    //**********************************************************

#if defined(HAVE_SCREEN) && defined(HAVE_VOLTAGE_DIVISOR)
    varioData.updateVoltage();
    screen.batLevel->setVoltage(varioData.voltage);
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

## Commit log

2019-09-19 SOURCE BETA - 0.5 Beta 7 PCB - V 2.1
    [Gnu Vario_E_V1.9.sch, Gnu vario V1.9.kicad_pcb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]
2019-09-26 Ajout fiche de présentation
2019-09-27 BOITIER 3D - Version 1.06 / ajout capuchon slide switch
    [capuchon slide switch.STL]
2019-10-18 PCB - Mise à jour PCB V2.1
    [BOM.xlsx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]
2019-10-18 SOURCE BETA - version 0.5 Beta 6 - testée sur PCBv2
2019-10-23 BOITIER 3D - Version 2.00
    [GNU bottom case belt 15mm screew for plastic 20mm.STL, GNU bottom case belt 15mm wood screw 20mm.STL, GNU bottom case belt 20mm screew for plastic 20mm.STL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]
2019-10-23 PCB - Version 2
    [BOM.xlsx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]
2019-11-04 Ajout RootSD, Calibration
2019-11-12 BOITIER 3D - Maj 1.52'' V2.01
    [GNU bottom case belt 15mm screew for plastic 20mm.STL, GNU bottom case belt 15mm wood screw 20mm.STL, GNU bottom case belt 20mm screew for plastic 20mm.STL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]
2019-11-28 SOURCE BETA - version 0.6 Beta 7
    [log.cfg, variocal.cfg, wifi.cfg]
2019-11-30 BOITIER 3D - Ajout 2.9''
    [cockpit GNU bottom case.STL, cockpit GNU top case.STL]
2019-12-08 Maj capuchon
    [GNU slide switch cap V2.STL]
2019-12-24 SOURCE BETA - version 0.7 Beta 3
    [log.cfg, variocal.cfg, wifi.cfg]
2020-01-11 SOURCE BETA - version 0.7 Beta 6
    [log.cfg, variocal.cfg, wifi.cfg]
2020-01-13 SOURCE BETA - Sdcard V0.7 beta 6
    [log.cfg, variocal.cfg, wifi.cfg]
2020-03-14 SOURCE BETA - version 0.7 beta 8 BOITIER 3D - version 2.01 - Boitier 2.9'' portrait
    [GNU bottom case 1000mAh 2.9.STL, GNU bottom case 2000mAh 2.9.STL, GNU slide switch cap V2.STL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]
2020-05-14 SOURCE BETA - version 0.8 beta 1
    [log.cfg, variocal.cfg, wifi.cfg]
2020-05-24 SOURCE BETA - version 0.8 beta 2
    [log.cfg, variocal.cfg, wifi.cfg]
2020-06-23 SOURCE BETA - version 0.8 beta 3
    [log.cfg, variocal.cfg, wifi.cfg]
2020-10-17 SOURCE BETA - version 0.8 beta 4
    [log.cfg, variocal.cfg, variosound.cfg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]
2020-10-18 SOURCE BETA - version 0.8 beta 4 - vscode
    [custompart.csv, variosound.cfg]
2020-12-13 SOURCE BETA - version 0.8 beta 5
    [custompart.csv, log.cfg, variocal.cfg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]
2020-12-21 SOURCE BETA - version 0.8 beta 5 - Corrections
    [Gnuvario-E.ino]
2021-04-19 Boitier 3D - version 2.05
    correction sur le boitier 1.54'' et 2.9'' portrait
    [GNU bottom case 1000mAh 2.9.STL, GNU bottom case 2000mAh 2.9.STL, GNU bottom case belt 15mm screew for plastic 20mm.STL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]
2021-06-12 SOURCE BETA - version 0.8 beta 6
    [log.cfg, variocal.cfg, variosound.cfg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]
2021-06-27 SOURCE BETA - version 0.8 beta 6 - Correction CAP + quelques bugs
    [Gnuvario-E.ino]
2021-06-29 ROOTSD - version 0.8 beta 6
    [variocal.cfg, variosound.cfg]

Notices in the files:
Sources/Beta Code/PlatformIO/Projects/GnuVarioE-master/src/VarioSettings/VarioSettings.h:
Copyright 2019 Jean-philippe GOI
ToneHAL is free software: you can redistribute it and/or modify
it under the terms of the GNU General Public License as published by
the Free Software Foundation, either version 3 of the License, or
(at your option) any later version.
